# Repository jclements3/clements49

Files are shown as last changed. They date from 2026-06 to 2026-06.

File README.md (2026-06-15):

# Clements 49

## Goal

Design a 49-string double-action concert pedal harp, voiced for church solo hymn playing and jazz, with a body of unidirectional + woven flax fabric, resin-infused (VARTM). Start from the TurboSquid model as the base geometry. Build the frame from flax resin-infused molds, and produce the brass parts by lost-wax / lost-PLA casting. Use multiple agents and CPUs working in parallel to achieve this goal.

## Specification

- **Strings:** 49 strings (0G to 7A; concert-tension nylon, gut, and wires)
- **Weight:** 96.5 lbs
- **Dimensions:** 75.5″ H × 40.5″ ExW

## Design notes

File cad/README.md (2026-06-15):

# Clements 49 — Parametric OpenSCAD Baseline

Parametric OpenSCAD model of the Clements 49, a 49-string double-action concert
pedal harp (flax/CF structure, brass action). This baseline exists to support
**structural and acoustic analysis** — above all, **perfecting the new soundbox
shape** — and is driven by a single-source-of-truth **string schedule** so that
the 47→49 string change propagates automatically through neck length/curve,
string spacing, soundboard length/taper, and disc/action counts.

Built for **OpenSCAD 2021.01**, authored in **millimetres**, world frame z-up,
origin at the base footprint centre, z=0 at the floor.

> `import()` in OpenSCAD 2021.01 supports **STL only**, not OBJ. The wooden
> 47-string TurboSquid base was therefore parsed to anchors (`analysis/`) and
> separately exported to STL (`reference/`) for a ghost overlay.

-----

## Directory layout

```
cad/
├── README.md              ← this file
├── MODULE_CONTRACT.md     ← per-module signatures every component honours
├── params.scad            ← all dims / anchors / tunables / colour + MATERIAL SWITCH
├── strings.scad           ← THE STRING SCHEDULE (single source of truth) + placement laws
├── assembly.scad          ← TOP-LEVEL model; assembles every component; toggles
├── frame/
│   ├── pillar.scad        ← module pillar()                    (flax tube / wood column)
│   ├── neck.scad          ← module neck(), neck_spine()        (woven-flax + CF spine)
│   ├── soundboard.scad    ← module soundboard(), _spine(), _wing(side)  (spine + wings)
│   ├── soundbox.scad      ← module soundbox(), soundbox_cavity(), soundbox_holes()
│   └── base.scad          ← module base() (+ pedal slots, mech cavity, CF junction pads)
├── brass/
│   └── brass.scad         ← tuning_pins(), sharping_discs(), action_plates(), pedals(), brass()
├── analysis/
│   ├── string_schedule.json   ← 49-row schedule (canonical machine source)
│   ├── string_schedule.csv    ← same, spreadsheet form
│   ├── anchors.json           ← geometry anchors from the base mesh (mm, z-up)
│   ├── raw_anchors.json       ← raw centroids before scaling/cleanup
│   ├── parse_obj.py           ← OBJ → anchors extraction
│   ├── finalize.py            ← schedule/anchor finalization
│   ├── load_basis_49.md       ← recomputed 49-string structural load basis
│   └── acoustic_baseline.md   ← cavity volume / Helmholtz / soundbox acoustic targets
└── reference/
    ├── export_stl.py          ← OpenSCAD-import helper (OBJ→STL via trimesh/blender)
    ├── whole_harp.stl         ← 47-string wooden base, full
    └── frame_only.stl         ← 47-string wooden base, frame only (ghost overlay)
```

`params.scad` and `strings.scad` are **include-only** files (data + functions,
no top-level geometry). Every component file `include`s both, so each resolves
all of its dimensions from the same source. `assembly.scad` `use<>`s the
component files (modules only, no stray self-preview) and `include`s the two
data files.

-----

## The string schedule is the single source of truth

`strings.scad` (data mirrored in `analysis/string_schedule.json` /
`.csv`) is the **one place** the instrument's string set is defined: 49 rows,
idx 0..48, each with note, octave, `f0_hz`, `vib_len_mm`, `tension_N`, and
material class (wire / gut-or-nylon-low / -mid / nylon-high).

Everything geometric is derived from it through functions, never hard-coded:

- **`string_count()` / `indices()`** — drive every per-string loop.
- **`string_pin_pos(i)`** — tuning-pin point on the neck pin-line → neck curve
  length and the count of tuning pins, ferrule seats, and sharping discs.
- **`string_t_board(i)` / board span** — the soundboard eyelet positions and
  the `board_span_mm` length.
- **Spacing law** (parametric, see below) — neck pin-line length and the
  soundboard span + bass→treble width taper.

### How 47 → 49 propagates

Changing the schedule from 47 to 49 rows is a **single data edit** in
`strings.scad`. From there:

- **Neck** — `neck()` hulls section slabs between every `string_pin_pos(i)`, so
  two extra pins lengthen the pin-line (~+20 mm) and the harmonic curve grows
  automatically; ferrule seats are punched at every pin.
- **String spacing** — two-locus spacing law (parametric):
  - **Neck (pin line):** essentially constant pitch `s_neck ≈ 10.0 mm`
    center-to-center, so 49 pins span (49−1)·10.0 = 480 mm of pin line.
  - **Soundboard (eyelet line):** spacing *grows treble→bass*,
    `s_board(idx) = s_treble + (s_bass − s_treble)·((48−idx)/48)^0.85`, with
    `s_treble = 6.5 mm`, `s_bass = 24.0 mm`. Its cumulative sum sets the board
    span (~1078 mm) and drives the 380→70 mm bass→treble width taper.
  - All four knobs (`s_neck`, `s_treble`, `s_bass`, exponent) are parameters.
- **Soundboard** — `board_span_mm` and the eyelet line follow the schedule;
  `board_taper_coupling` ties the bass-wing growth to the spacing law.
- **Soundbox** — adds a synthetic bass-extension station below section 0 so the
  bass corner reaches ~50 mm farther to host the new bass string (B0).
- **Brass** — `tuning_pins()`=49, `action_discs()`=2·49=98, `pedals()`=7 (fixed
  by the diatonic-class system), action-plate segments `ceil(49/1.6)=31`.

### Resolving the "0G–7A" / 49-string spec naming

The spec calls for **49 strings labeled "0G–7A"**. The standard concert pedal
harp is **47 strings = C1..G7** (oct1 C1–B1 = 7; oct2–6 = 5×7 = 35; oct7 C7–G7
= 5; total 47). A strictly contiguous diatonic run does **not** cleanly give
"G..A" endpoints at exactly 49 from a single literal reading, so the spec is read
as octave-block extremes (bottom block "0", top block "7") rather than literal
end-string letters, and the conflict is stated rather than papered over.

**Adopted resolution (per project direction):** keep the standard 47-string
C1..G7 core and add **both** extra strings in the **bass** — **A0** and **B0**,
the two diatonic steps below C1. Treble caps at **G7** (no A7). Final range =
**A0 .. G7 = 49 strings** (idx 0 = A0, idx 48 = G7). Every string is a natural;
the double-action pedals raise each diatonic class 0/1/2 semitones, so the
schedule is the all-natural reference set, A4 = 440 Hz, equal temperament.

**Justification.** *Acoustic:* a two-string bass extension (A0 ≈ 27.5 Hz, B0 ≈
30.9 Hz) puts the most added fundamental weight exactly where the church/hymn
solo voice works hardest — the bottom octave — and grows the bass corner of the
soundbox/board where the extra cavity and radiating area are wanted. *Structural:*
both strings at the bass end extend the neck pin line (~+35 mm) and board (~+81 mm)
at one corner; the load basis is recomputed on this real geometry (see below).

**Mapping to the base model:** idx 0 (A0) and idx 1 (B0) are NEW groups inserted
below `harp_string_00`; idx 2..48 map to `harp_string_00..46` (the original
C1..G7). The measured 47-string anchor endpoints are re-anchored to C1 (idx 2)
and G7 (idx 48); A0,B0 extrapolate below the bass end (`strings.scad`
`ORIG_BASS_IDX`/`ORIG_TREBLE_IDX`). Disc/action and tuning-pin counts increase
from 47 to 49 (two new fork/discs + pins at the bass end).

-----

## Material switch: wood ↔ flax

The master switch is **one line** in `params.scad`: `material = "flax"`. It
selects the committed flax-resin structure (materials.md §6) or the wooden
47-string reference. Components **never branch on `material` directly** — they
read only the params accessors (`wall_soundbox()`, `soundboard_thickness()`,
`pillar_od()/pillar_wall()`, `wall_base()`, colour helpers `as_shell()`,
`as_carbon()`, `as_tonewood()`, `as_brass()`), so the switch drives thickness,
section, hidden CF spine presence, and colour uniformly.

Because each component `include`s its own copy of `params.scad` (an include is a
variable import; the last file-scope assignment wins), the canonical way to flip
the **whole** instrument is to edit that one line **or** drive it from the CLI:

```
openscad -D 'material="flax"' cad/assembly.scad   # committed flax-resin (default)
openscad -D 'material="wood"' cad/assembly.scad   # wooden 47-string-style reference
```

Representative differences the switch produces: pillar 50 mm OD / 8 mm wall hollow
flax tube vs 60 mm solid wood column; soundboard 10.2 mm flax sandwich
(2×1.6 skin + 7.0 core) vs 13.1 mm solid plate; base 6 mm flax monocoque vs 18 mm
solid wood; the CF spine in `neck`/`soundboard` is emitted only in flax mode.
**Brass action parts stay brass in both builds** (real harps use brass action
regardless), so brass geometry does not branch on `material`.

-----

## Soundbox tunables — perfecting the new shape

The soundbox is the analysis focus. All knobs live in `params.scad` (acoustic
group) and feed `frame/soundbox.scad`; the cross-section is a super-ellipse whose
exponent comes from `cavity_fill_factor` and whose semi-axes are area-normalised
so integrated cavity area = `cavity_fill_factor` × bounding-ellipse area.
`soundbox_cavity()` returns the inner air volume as a positive solid for
Helmholtz / volume analysis. At default `cavity_fill_factor = 0.62` the cavity
measures ~45.6 L (acoustic_baseline.md target ~45.4 L, band 40–51 L).

| Tunable | Effect | Range (default) |
|---|---|---|
| `cavity_fill_factor` | wedge↔full-ellipse cross-section → cavity volume / Helmholtz pitch | 0.55–0.70 (0.62) |
| `body_depth_profile` | per-station depth multiplier; deeper = more volume, lower f_H, warmer | 0.85–1.20× |
| `body_width_profile` | per-station across-string width; widens bass corner | 0.85–1.20× |
| `body_length_scale` | stretch of the bass→treble long axis (tracks schedule span) | 1.00–1.10 |
| `bass_corner_bulge` | extra depth+width at the lowest sections for the B0 extension | 1.00–1.25 |
| `back_curvature_radius` | transverse crown radius of the back shell | 200 mm → flat (∞) |
| `back_liveness` | back-panel compliance dead↔live (thins back skin) | 0 (dead) – 1 (live) |
| `soundhole_count` | number of back soundholes → total area S, f_H, Q | 3–6 (5) |
| `soundhole_scale` | global hole-area multiplier → Helmholtz pitch / damping | 0.7–1.4× |
| `soundhole_grade_exp` | bass→treble hole-size grading exponent | 0.5–1.5 |
| `soundhole_axis_offset` | hole-column placement along back centreline | 0.2–0.8 of length |
| `wall_thickness` | flax shell wall (Helmholtz L_eff, shell stiffness/mass) | 3–6 mm |

Coupled board knobs (`board_span`, `board_width_bass/treble`, `board_crown_radius`,
`core_depth`, `skin_thickness`, `board_taper_coupling`) also live in the same
group; `board_span` and the taper are single-sourced from the schedule.

-----

## Rendering

```
# Preview / render the whole instrument:
openscad cad/assembly.scad

# Headless STL render:
openscad -o /tmp/clements49.stl cad/assembly.scad
```

Top-level toggles in `assembly.scad` (override on the CLI with `-D name=true/false`):

| Toggle | Default | Shows |
|---|---|---|
| `show_frame` | true | pillar + neck + soundboard + soundbox + base |
| `show_brass` | true | tuning pins + sharping discs + action plates + pedals |
| `show_strings` | true | simple cylinders straight from the schedule |
| `show_reference` | false | faint STL ghost of the 47-string wooden base |
| `show_cavity` | false | soundbox inner air volume (analysis aid) |

Example: render just the soundbox cavity for volume study —
`openscad -D show_frame=false -D show_brass=false -D show_strings=false -D show_cavity=true cad/assembly.scad`.

Each component file also has a `$preview`-guarded self-preview, so opening it
alone in the GUI shows that part, while headless `-o` export of the bare file
emits nothing (by design — see verify notes below).

-----

## MOLDS DEFERRED

**No casting molds or mold cavities are generated in this baseline, by hard
directive.** The two added strings will move geometry (neck curve, board
span/taper, soundbox bass corner), so any mold authored now would be obsolete
the moment the schedule or soundbox tunables move. **Analysis and the parametric
baseline come first; molds come only after the geometry is frozen.**

What is in place instead are clean **hooks**, so adding molds later is additive,
not a rewrite:

- Every structural part is authored as a **single positive module** that a future
  offset-shell can wrap (`pillar()`, `neck()/neck_spine()`,
  `soundboard()/_spine()/_wing()`, `soundbox()/soundbox_cavity()`, `base()`).
  Each file carries a comment marking where a casting-pattern / mold-cavity
  offset-shell would attach.
- `soundbox_cavity()` already returns the inner volume as a positive solid —
  the natural seed for a future core/cavity tool.
- Brass: `brass_pattern_scale()` (= 1.015, the 1.5 % shrink oversize) is defined
  and referenced **only in comments/echo** as a future opt-in pattern step; it is
  never applied to as-used geometry. No sprue, gating, or cavities exist.

When the geometry is frozen, mold work wraps these modules — it does not modify
them.

-----

## Verify results (honest)

OpenSCAD 2021.01. Each file was parse/eval-checked (`-o …csg`) and, where it
produces geometry, render-checked to STL.

| File | Parse/eval | Render | Notes |
|---|---|---|---|
| `params.scad` | PASS (exit 0, no errors) | n/a | Include-only (params + functions, no top-level geometry). STL export reports "Current top level object is empty" and exits non-zero — **expected and acceptable** for an include-only file. No ERROR. |
| `strings.scad` | PASS (exit 0, no errors) | n/a | Include-only (schedule data + functions). Empty-top-level on export, as designed. No ERROR. No code changes. |
| `frame/pillar.scad` | PASS | PASS | Renders in flax (default) and wood (`-D material="wood"`). |
| `frame/neck.scad` | PASS | PASS | Hull sweep renders to a valid non-empty STL (~86 KB). |
| `frame/soundboard.scad` | PASS (exit 0; 3 info ECHOes: material=flax, U_len=1078 mm, eyelets=49) | PASS | Bare-file headless export emits nothing — top-level geometry is guarded by `if (sb_preview && $preview)`; `$preview` is false under `-o`. A wrapper calling `soundboard();` renders a manifold solid (222 facets, 438 verts, 2 volumes, ~10 s, 46 KB). Guard is the idiomatic include-by-assembly pattern; not changed. |
| `frame/soundbox.scad` | PASS (exit 0; ECHO diagnostics only) | **`render_ok=false` for the bare file, BY DESIGN** | Top-level geometry is guarded at line 336 by `if ($preview) _soundbox_selfpreview();`; `$preview` is false under `-o`, so bare-file export yields an empty top level (~47 KB stub, no real geometry, exit 1). This is a library meant to be `use<>`d by the assembly, like `params`/`strings`. **The geometry itself is valid:** via the assembly / a direct call, `soundbox()` renders a watertight solid (2408 facets), wood override renders, and `soundbox_cavity()` measures **45.6 L** (target 45.4 L). No ERROR; no syntax fix applied (changing the guard would be a redesign, not a low-risk fix). |
| `frame/base.scad` | PASS (exit 0; ECHO diagnostics) | PASS | Module-definition file; top-level call guarded by `PREVIEW_base = false`. With `-D material="wood" -D PREVIEW_base=true` renders a valid manifold (41 facets, 2 volumes). |
| `brass/brass.scad` | PASS | PASS | Full STL render completes, no errors/warnings (~7.8 MB mesh; 49 pins, 98 discs, 31 plate segs, 7 pedals). |
| `assembly.scad` | PASS | PASS | Top-level model assembles cleanly. |

**Summary:** all nine files parse/eval with exit 0 and **no ERROR output**.
Every geometry-producing module renders to a valid manifold STL when invoked
(directly or via the assembly). The only `render_ok=false` is `soundbox.scad`'s
*bare-file* headless export, which is the intended `$preview`-guarded
empty-top-level condition for a library file — not a defect. No syntax errors
were found and no code was changed during verification.

### Known follow-ups (carried in the analysis, not yet applied)

- The neck curve currently lerps a straight chord between the measured 47-string
  pin-line endpoints rather than threading the full curved tuning-pin polyline;
  refitting the harmonic arc to the regenerated 49-pin polyline needs
  `strings.scad` to expose intermediate curve control points (out of scope here).
- `pin_line_bass/treble_mm` in `params.scad` are still the **47-string** anchor
  values; disc/plate counts already scale to 49, but the pin-line endpoints
  should be re-derived once the neck refits for +1 bass / +1 treble (~+20 mm).
- Part dimensions for brass (pin/disc/plate/pedal sizes) are `[est]` placeholders
  flagged inline.
- Per `analysis/load_basis_49.md`, the structural load basis should be re-run on
  the regenerated 49-pin line once the neck/board geometry is refit.

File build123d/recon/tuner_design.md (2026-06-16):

# Compact brass worm-drive harp tuner — design concept

Adapts the worm-and-wheel principle of the "Guitar tuners that actually work" design
(noamtsvi, CC-BY-NC — concept only, not their geometry) into a harp-appropriate
**brass** geared tuner that replaces the simple turned pin. Self-locking worm gearing
gives fine, stable tuning that holds string tension.

## Architecture (per string)
- **String post** — Ø4.5 mm brass post with a Ø1.2 mm string hole; the string winds on it
  (replaces the pin). The worm **wheel** is integral with / fixed to the post.
- **Worm wheel** — module 0.4, 10 teeth, pitch Ø4.0 / OD Ø4.8 mm.
- **Worm** — single-start (z1=1), pitch Ø5.0 / OD Ø5.8 mm; **lead angle 4.6°** → self-locking
  (< friction angle, so string tension cannot back-drive it). Ratio **10:1**.
- **Drive** — a **hex socket** (4 mm A/F) on the worm's outboard end; turned with a hex
  driver (no finger knob). Worm axis points OUTWARD (toward the player), where there's room.
- **Brass receiver** — cast brass body **co-moulded into the VARTM flax-resin neck**: placed
  in the mould, flax/resin infuses around it and keys into its anchor holes. Carries the
  string load into the composite and provides the post + worm bearing bores. The tuner
  assembles into the receiver.

## Packaging (the binding constraint: neck pitch)
Footprint **along the neck = 11.4 mm**; outward (toward player) = 14.0 mm (room there).
Adjacent-pin pitch on the neck: treble 11.7, median 18.7, bass ≥30 mm.

| region | pitch | fit |
|---|---|---|
| treble | 11.7 mm | FITS, **+0.3 mm only** — razor-thin, no tolerance margin |
| median | 18.7 mm | fits, +7.3 mm |
| bass | ≥30 mm | fits, +18.6 mm |

The unit is asymmetric (worm to one side), so the post is **not centred** in its slot;
units must all nest the same handedness.

## Coupled trade-offs
- **Self-locking vs fit:** a low lead angle (self-locking) wants a larger worm; fit wants
  small gears. Reconciled at module 0.4 / worm Ø5.0 / wheel Ø4.8, but the teeth are small.
- **Strength:** worm-wheel torque ≈ string_tension × post_radius ≈ 261 N × 2.25 mm ≈ 587 N·mm
  at the bass. Module-0.4 brass teeth holding 100–261 N need a **tooth-root stress check**
  before finalising. The bass (highest load) has the most room → can use bigger gears there.

## Honest recommendation
Geared tuners are viable across the bass and mid. The **treble is marginal** (0.3 mm). Options:
1. **Two gear sizes** — robust gears on bass/mid, minimum gears on treble.
2. **Plain turned pins on the top ~octave** (lowest tension, easiest to tune) + geared elsewhere.
3. Push module to 0.35 and/or nest receivers front/back along the neck for the treble.

## Status / next
Packaging + gear sizing validated (`tuner_concept.py` → `tuner_concept.svg`,
`tuner_params.json`). NEXT: build the 3D parametric brass parts (receiver, post+wheel,
worm) in build123d, verify the assembly within the envelope, then tooth-stress check.
Tooth geometry in the concept is representational; cuttable involute/worm teeth are a
dedicated step (or sourced gears).

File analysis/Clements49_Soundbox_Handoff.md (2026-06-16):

# Clements 49 — Limaçon Soundbox: Geometry Handoff

A flax-composite soundbox for the 49-string (A0–G7) "Clements 49" concert pedal harp,
voiced warm. The cross-section is a **limaçon of Pascal**. This document fixes the
geometry, the orientation frame, the wall logic, and where the soundboard Bézier plugs
in, and ends with a runnable SVG of the section and an OpenSCAD generator.

---

## 1. The one-line idea

> **Outer mold line = a limaçon at `a:b = 2`** (so the stringbar lands on a *flat*),
> **inner mold line = a free-form graded wall** (thin to sing, ribbed to hold the
> string tension). Sections are cut perpendicular to the raked stringbar and lofted
> bass→treble; the soundboard outline only sets how wide each section is.

---

## 2. Coordinate frame & orientation

All from the 49 board pins (the grommet line) in `strings_49.json`. The stringbar axis
is the principal axis of those pins.

| vector | value | meaning |
|---|---|---|
| `û` (U_AXIS) | `[0.523, 0, 0.852]` | stringbar axis, raked **31.6°** from vertical, lies in the x–z plane |
| `ŷ` (Y_MINOR) | `[0, 1, 0]` | soundboard **width** direction = limaçon **minor** side |
| `n̂` (N_BOARD) | `[-0.852, 0, 0.523]` | soundboard **normal**, in x–z |
| belly | `[0.852, 0, -0.523]` = −n̂ | dimple→belly, hangs **underneath** (−z) |

**Section plane is perpendicular to `û`.** Its two in-plane axes are `ŷ` and `n̂`, and
`ŷ × n̂ = û` (right-handed), which is why the two limaçon diameters land in *different*
coordinate planes:

- **minor axis (width)** runs along **`ŷ`** → reads in the **y–z** plane;
- **major axis (depth / belly)** runs along **`n̂`** → reads in the **x–z** plane, going −z.

That split is not a contradiction — it's what happens when the section plane is tilted
(perpendicular to a raked axis) instead of aligned to a coordinate plane.

---

## 3. Cross-section geometry

### 3.1 Outer = limaçon, `a:b = 2`  (the flat seat)

Polar form `r = a + b·cos θ`. Convexity is governed by the sign of
`g(θ) = r² + 2r′² − r·r″`, which for this curve reduces to

```
g(θ) = a² + 3ab·cos θ + 2b²
g_min = g(π) = a² − 3ab + 2b² = (a − b)(a − 2b)
```

| ratio | `g_min` | shape |
|---|---|---|
| `a < b` | — | inner loop (curve threads the origin) |
| `a = b` | — | cardioid (cusp at origin) |
| `b < a < 2b` | `< 0` | **dimpled** — genuine concave indentation |
| **`a = 2b`** | **`= 0`** | **flat point at θ=π — convex boundary** |
| `a > 2b` | `> 0` | strictly convex (egg) |

We use **`a = 2b`** for the outer: at θ=π the curvature is exactly zero, so the outer
surface is **flat** right where the stringbar meets it. A straight bar wants a flat seat,
not a pocket — that is the whole reason for the choice. (Earlier drafts used `a < 2b`,
which puts a *concave* dent there; wrong for a straight bar.)

At `a:b = 2` the section is **380 wide × 345 deep** at the bass, ratio **d/w = 0.91**.

### 3.2 Inner = free-form graded wall

The inner curve is **not** a limaçon and is not tied to `a:b`. It is the outer offset
inward by a thickness `t(θ)` that varies around the section. That single freedom carries
the structural job without touching the outer shape.

---

## 4. The proportions lesson (why this split is the fix)

A *true* limaçon has its width-to-depth ratio **locked** by `a:b` — for every dimpled
ratio the perpendicular width is the *larger* dimension and the dimple→belly depth the
*smaller* one. You cannot independently choose width and depth and still have a limaçon;
forcing it (scaling x and y by different factors) breaks `r = a + b·cos θ` and yields a
distorted egg, not a limaçon.

The resolution: **only the outer is a true limaçon** (fixed `a:b = 2`, fixed 0.91 ratio,
scaled uniformly by the soundboard width). **The inner is free**, so all the
thick/thin tuning lives there. No stretching, no conflict.

---

## 5. Wall-thickness rationale

The strings pull **ΣT ≈ 9,269 N** total, of which **~5 kN** presses down through the
grommets onto the board, as a line load along the stringbar (θ=180). The grading follows
that load path:

| zone | θ | thickness | why |
|---|---|---|---|
| **rib** | ≈ 180° (stringbar line) | **~24 mm** | takes the concentrated string-anchor / down-bearing load |
| **radiating board** | flanks of θ=180° | **~3.5 mm** | this face is the radiator; thin = it moves freely |
| **structural belly** | ≈ 0° (back) | **~8 mm** | closes the box, carries the reaction, radiates less |

This is the "thick enough to hold / thin enough to sing" requirement, resolved by
**grading the inner wall**, not by one uniform thickness. The rib carries the load so the
board on either side can stay thin and vibrate.

> **Caveat — these thicknesses are first-pass.** They were set with representative
> flax-composite stiffness to fix the *proportions*, not your layup. Final values need
> your fiber fraction / ply schedule and an FEA pass. Treat them as the starting point,
> not the answer.

---

## 6. Soundboard Bézier control

The soundboard outline is (almost) a **teardrop**: fat rounded bass tapering to a treble
point. Its **half-width along the stringbar is the only thing it controls** — it sets how
wide each limaçon section is, station by station. Nothing else in the geometry depends on
it.

In the generator this is the single function:

```scad
function w_half(s) = HW_BASS * pow(1 - s, TEAR_EXP);   // first-cut teardrop
```

Replace the body with your Bézier evaluated at `s ∈ [0,1]` (bass→treble) returning the
**half-width in mm**. Everything downstream — outer scale, inner offset, the loft —
updates automatically. The outer `a:b` stays 2 regardless.

---

## 7. Acoustic note (independent of section shape)

The A0 cavity (Helmholtz) resonance is driven by **volume and the back sound-holes**, not
the cross-section profile. Target **A0 ≈ 130 Hz**, placed just under the first board mode
(~150 Hz), which wants **~35 L** behind the board plus the graded back holes
(~240 cm² total, 5 holes). The holes are **not** cut by the generator — subtract them from
the belly face afterward. Changing `a:b`, the teardrop, or the wall does not move A0 as
long as the enclosed volume is held.

---

## 8. Lessons learned (so they don't recur)

1. **Superellipses are not limaçons.** `y = D(1−|2x/W|ⁿ)^{1/n}` is a superellipse; don't
   label it limaçon-family.
2. **Sections are perpendicular to the *raked* stringbar**, not cut in horizontal
   (constant-z) planes. The board is raked ~32°.
3. **Axes:** width = `ŷ` (minor, y–z); depth/belly = `n̂` (major, x–z, −z). Don't swap
   them; the soundboard width is the y extent, not the x–z one.
4. **Never anisotropically scale a limaçon** to hit an arbitrary W×D box — it stops being
   a limaçon (the "weird ellipse"). Uniform scale only.
5. **The outer dimple is `a = 2b` (flat), not `a < 2b` (concave).** A straight stringbar
   seats on a flat. The tension thickening belongs to the **inner** wall, which is free.

---

## 9. Open items

- [ ] Replace `w_half(s)` with the real soundboard Bézier (half-width profile).
- [ ] Final wall thicknesses from your flax layup + FEA (current values are first-pass).
- [ ] Cut the 5 back sound-holes from the belly face; tune total area to hold A0 ≈ 130 Hz.
- [ ] Reconcile the ~10–20% frame scatter between `strings_49.json` and the earlier
      `soundbox_reloft_data.json` once rendered against the real STLs.
- [ ] Render the OpenSCAD (I can't here) and confirm the polyhedron is manifold /
      right-side-out.

---

## 10. Section — SVG (bass station)

```svg
<svg xmlns="http://www.w3.org/2000/svg" viewBox="0 0 600 470" font-family="sans-serif">
  <!-- wall = outer with inner as even-odd hole -->
  <path d="M300.0,405.2 L310.9,404.9 L321.8,404.0 L332.6,402.5 L343.3,400.3 L353.8,397.6 L364.1,394.3 L374.2,390.5 L384.1,386.0 L393.6,381.1 L402.9,375.6 L411.8,369.7 L420.3,363.3 L428.3,356.5 L436.0,349.3 L443.2,341.7 L449.9,333.7 L456.2,325.5 L461.9,317.0 L467.1,308.2 L471.8,299.2 L475.9,290.1 L479.6,280.9 L482.6,271.5 L485.2,262.1 L487.2,252.6 L488.6,243.2 L489.6,233.8 L490.0,224.4 L489.9,215.2 L489.4,206.1 L488.4,197.1 L486.9,188.4 L485.0,179.8 L482.7,171.5 L480.0,163.4 L476.9,155.6 L473.5,148.1 L469.8,140.9 L465.8,134.0 L461.5,127.5 L457.0,121.3 L452.3,115.4 L447.4,109.8 L442.4,104.6 L437.2,99.8 L432.0,95.3 L426.6,91.1 L421.2,87.3 L415.8,83.7 L410.3,80.5 L404.8,77.6 L399.4,75.0 L394.0,72.7 L388.7,70.6 L383.4,68.8 L378.3,67.2 L373.2,65.8 L368.2,64.7 L363.3,63.7 L358.5,62.8 L353.9,62.1 L349.3,61.6 L344.9,61.1 L340.5,60.8 L336.3,60.5 L332.2,60.3 L328.2,60.2 L324.2,60.1 L320.4,60.1 L316.6,60.0 L312.8,60.0 L309.1,60.0 L305.5,60.0 L301.8,60.0 L298.2,60.0 L294.5,60.0 L290.9,60.0 L287.2,60.0 L283.4,60.0 L279.6,60.1 L275.8,60.1 L271.8,60.2 L267.8,60.3 L263.7,60.5 L259.5,60.8 L255.1,61.1 L250.7,61.6 L246.1,62.1 L241.5,62.8 L236.7,63.7 L231.8,64.7 L226.8,65.8 L221.7,67.2 L216.6,68.8 L211.3,70.6 L206.0,72.7 L200.6,75.0 L195.2,77.6 L189.7,80.5 L184.2,83.7 L178.8,87.3 L173.4,91.1 L168.0,95.3 L162.8,99.8 L157.6,104.6 L152.6,109.8 L147.7,115.4 L143.0,121.3 L138.5,127.5 L134.2,134.0 L130.2,140.9 L126.5,148.1 L123.1,155.6 L120.0,163.4 L117.3,171.5 L115.0,179.8 L113.1,188.4 L111.6,197.1 L110.6,206.1 L110.1,215.2 L110.0,224.4 L110.4,233.8 L111.4,243.2 L112.8,252.6 L114.8,262.1 L117.4,271.5 L120.4,280.9 L124.1,290.1 L128.2,299.2 L132.9,308.2 L138.1,317.0 L143.8,325.5 L150.1,333.7 L156.8,341.7 L164.0,349.3 L171.7,356.5 L179.7,363.3 L188.2,369.7 L197.1,375.6 L206.4,381.1 L215.9,386.0 L225.8,390.5 L235.9,394.3 L246.2,397.6 L256.7,400.3 L267.4,402.5 L278.2,404.0 L289.1,404.9 L300.0,405.2 Z M299.8,397.2 L310.5,396.9 L320.9,396.1 L331.2,394.6 L341.5,392.6 L351.6,390.0 L361.5,386.8 L371.2,383.2 L380.7,378.9 L389.9,374.2 L398.7,369.0 L407.3,363.4 L415.4,357.3 L423.2,350.8 L430.6,343.9 L437.6,336.6 L444.1,329.0 L450.1,321.2 L455.7,313.0 L460.7,304.6 L465.3,296.1 L469.3,287.3 L472.9,278.5 L475.9,269.5 L478.4,260.4 L480.4,251.4 L481.9,242.3 L482.9,233.3 L483.4,224.3 L483.4,215.4 L483.0,206.6 L482.1,198.0 L480.8,189.6 L479.0,181.3 L476.9,173.3 L474.4,165.5 L471.5,157.9 L468.3,150.7 L464.8,143.7 L461.0,137.0 L457.0,130.6 L452.7,124.5 L448.3,118.8 L443.6,113.4 L438.8,108.3 L433.9,103.5 L428.8,99.1 L423.7,95.0 L418.5,91.2 L413.3,87.7 L408.1,84.6 L402.8,81.7 L397.6,79.1 L392.4,76.7 L387.2,74.7 L382.1,72.8 L377.1,71.2 L372.2,69.8 L367.3,68.6 L362.6,67.6 L357.9,66.7 L353.3,66.0 L348.9,65.4 L344.5,64.9 L340.3,64.5 L336.1,64.3 L332.0,64.3 L328.0,64.6 L324.1,65.4 L320.3,67.1 L316.5,69.9 L312.8,73.6 L309.1,77.7 L305.5,81.5 L301.8,83.7 L298.2,83.7 L294.5,81.5 L290.9,77.7 L287.2,73.6 L283.5,69.9 L279.7,67.1 L275.9,65.4 L272.0,64.6 L268.0,64.3 L263.9,64.3 L259.7,64.5 L255.5,64.9 L251.1,65.4 L246.7,66.0 L242.1,66.7 L237.4,67.6 L232.7,68.6 L227.8,69.8 L222.9,71.2 L217.9,72.8 L212.8,74.7 L207.6,76.7 L202.4,79.1 L197.2,81.7 L191.9,84.6 L186.7,87.7 L181.5,91.2 L176.3,95.0 L171.2,99.1 L166.1,103.5 L161.2,108.3 L156.4,113.4 L151.7,118.8 L147.3,124.5 L143.0,130.6 L139.0,137.0 L135.2,143.7 L131.7,150.7 L128.5,157.9 L125.6,165.5 L123.1,173.3 L121.0,181.3 L119.2,189.6 L117.9,198.0 L117.0,206.6 L116.6,215.4 L116.6,224.3 L117.1,233.3 L118.1,242.3 L119.6,251.4 L121.6,260.4 L124.1,269.5 L127.1,278.5 L130.7,287.3 L134.7,296.1 L139.3,304.6 L144.3,313.0 L149.9,321.2 L155.9,329.0 L162.4,336.6 L169.4,343.9 L176.8,350.8 L184.6,357.3 L192.7,363.4 L201.3,369.0 L210.1,374.2 L219.3,378.9 L228.8,383.2 L238.5,386.8 L248.4,390.0 L258.5,392.6 L268.8,394.6 L279.1,396.1 L289.5,396.9 L300.2,397.2 Z" fill="#b9966a" fill-rule="evenodd" stroke="none"/>
  <path d="M300.0,405.2 L310.9,404.9 L321.8,404.0 L332.6,402.5 L343.3,400.3 L353.8,397.6 L364.1,394.3 L374.2,390.5 L384.1,386.0 L393.6,381.1 L402.9,375.6 L411.8,369.7 L420.3,363.3 L428.3,356.5 L436.0,349.3 L443.2,341.7 L449.9,333.7 L456.2,325.5 L461.9,317.0 L467.1,308.2 L471.8,299.2 L475.9,290.1 L479.6,280.9 L482.6,271.5 L485.2,262.1 L487.2,252.6 L488.6,243.2 L489.6,233.8 L490.0,224.4 L489.9,215.2 L489.4,206.1 L488.4,197.1 L486.9,188.4 L485.0,179.8 L482.7,171.5 L480.0,163.4 L476.9,155.6 L473.5,148.1 L469.8,140.9 L465.8,134.0 L461.5,127.5 L457.0,121.3 L452.3,115.4 L447.4,109.8 L442.4,104.6 L437.2,99.8 L432.0,95.3 L426.6,91.1 L421.2,87.3 L415.8,83.7 L410.3,80.5 L404.8,77.6 L399.4,75.0 L394.0,72.7 L388.7,70.6 L383.4,68.8 L378.3,67.2 L373.2,65.8 L368.2,64.7 L363.3,63.7 L358.5,62.8 L353.9,62.1 L349.3,61.6 L344.9,61.1 L340.5,60.8 L336.3,60.5 L332.2,60.3 L328.2,60.2 L324.2,60.1 L320.4,60.1 L316.6,60.0 L312.8,60.0 L309.1,60.0 L305.5,60.0 L301.8,60.0 L298.2,60.0 L294.5,60.0 L290.9,60.0 L287.2,60.0 L283.4,60.0 L279.6,60.1 L275.8,60.1 L271.8,60.2 L267.8,60.3 L263.7,60.5 L259.5,60.8 L255.1,61.1 L250.7,61.6 L246.1,62.1 L241.5,62.8 L236.7,63.7 L231.8,64.7 L226.8,65.8 L221.7,67.2 L216.6,68.8 L211.3,70.6 L206.0,72.7 L200.6,75.0 L195.2,77.6 L189.7,80.5 L184.2,83.7 L178.8,87.3 L173.4,91.1 L168.0,95.3 L162.8,99.8 L157.6,104.6 L152.6,109.8 L147.7,115.4 L143.0,121.3 L138.5,127.5 L134.2,134.0 L130.2,140.9 L126.5,148.1 L123.1,155.6 L120.0,163.4 L117.3,171.5 L115.0,179.8 L113.1,188.4 L111.6,197.1 L110.6,206.1 L110.1,215.2 L110.0,224.4 L110.4,233.8 L111.4,243.2 L112.8,252.6 L114.8,262.1 L117.4,271.5 L120.4,280.9 L124.1,290.1 L128.2,299.2 L132.9,308.2 L138.1,317.0 L143.8,325.5 L150.1,333.7 L156.8,341.7 L164.0,349.3 L171.7,356.5 L179.7,363.3 L188.2,369.7 L197.1,375.6 L206.4,381.1 L215.9,386.0 L225.8,390.5 L235.9,394.3 L246.2,397.6 L256.7,400.3 L267.4,402.5 L278.2,404.0 L289.1,404.9 L300.0,405.2 Z" fill="none" stroke="#5a2d0c" stroke-width="2.2"/>
  <path d="M299.8,397.2 L310.5,396.9 L320.9,396.1 L331.2,394.6 L341.5,392.6 L351.6,390.0 L361.5,386.8 L371.2,383.2 L380.7,378.9 L389.9,374.2 L398.7,369.0 L407.3,363.4 L415.4,357.3 L423.2,350.8 L430.6,343.9 L437.6,336.6 L444.1,329.0 L450.1,321.2 L455.7,313.0 L460.7,304.6 L465.3,296.1 L469.3,287.3 L472.9,278.5 L475.9,269.5 L478.4,260.4 L480.4,251.4 L481.9,242.3 L482.9,233.3 L483.4,224.3 L483.4,215.4 L483.0,206.6 L482.1,198.0 L480.8,189.6 L479.0,181.3 L476.9,173.3 L474.4,165.5 L471.5,157.9 L468.3,150.7 L464.8,143.7 L461.0,137.0 L457.0,130.6 L452.7,124.5 L448.3,118.8 L443.6,113.4 L438.8,108.3 L433.9,103.5 L428.8,99.1 L423.7,95.0 L418.5,91.2 L413.3,87.7 L408.1,84.6 L402.8,81.7 L397.6,79.1 L392.4,76.7 L387.2,74.7 L382.1,72.8 L377.1,71.2 L372.2,69.8 L367.3,68.6 L362.6,67.6 L357.9,66.7 L353.3,66.0 L348.9,65.4 L344.5,64.9 L340.3,64.5 L336.1,64.3 L332.0,64.3 L328.0,64.6 L324.1,65.4 L320.3,67.1 L316.5,69.9 L312.8,73.6 L309.1,77.7 L305.5,81.5 L301.8,83.7 L298.2,83.7 L294.5,81.5 L290.9,77.7 L287.2,73.6 L283.5,69.9 L279.7,67.1 L275.9,65.4 L272.0,64.6 L268.0,64.3 L263.9,64.3 L259.7,64.5 L255.5,64.9 L251.1,65.4 L246.7,66.0 L242.1,66.7 L237.4,67.6 L232.7,68.6 L227.8,69.8 L222.9,71.2 L217.9,72.8 L212.8,74.7 L207.6,76.7 L202.4,79.1 L197.2,81.7 L191.9,84.6 L186.7,87.7 L181.5,91.2 L176.3,95.0 L171.2,99.1 L166.1,103.5 L161.2,108.3 L156.4,113.4 L151.7,118.8 L147.3,124.5 L143.0,130.6 L139.0,137.0 L135.2,143.7 L131.7,150.7 L128.5,157.9 L125.6,165.5 L123.1,173.3 L121.0,181.3 L119.2,189.6 L117.9,198.0 L117.0,206.6 L116.6,215.4 L116.6,224.3 L117.1,233.3 L118.1,242.3 L119.6,251.4 L121.6,260.4 L124.1,269.5 L127.1,278.5 L130.7,287.3 L134.7,296.1 L139.3,304.6 L144.3,313.0 L149.9,321.2 L155.9,329.0 L162.4,336.6 L169.4,343.9 L176.8,350.8 L184.6,357.3 L192.7,363.4 L201.3,369.0 L210.1,374.2 L219.3,378.9 L228.8,383.2 L238.5,386.8 L248.4,390.0 L258.5,392.6 L268.8,394.6 L279.1,396.1 L289.5,396.9 L300.2,397.2 Z" fill="none" stroke="#7a3b10" stroke-width="1.3"/>
  <!-- stringbar on the flat outer -->
  <line x1="150" y1="58" x2="450" y2="58" stroke="#0f5c4d" stroke-width="4"/>
  <circle cx="300" cy="60" r="5" fill="#0f5c4d"/>
  <!-- string stubs -->
  <line x1="180" y1="44" x2="180" y2="58" stroke="#3b7bbf" stroke-width="1"/><line x1="210" y1="44" x2="210" y2="58" stroke="#3b7bbf" stroke-width="1"/><line x1="240" y1="44" x2="240" y2="58" stroke="#3b7bbf" stroke-width="1"/><line x1="270" y1="44" x2="270" y2="58" stroke="#3b7bbf" stroke-width="1"/><line x1="300" y1="44" x2="300" y2="58" stroke="#3b7bbf" stroke-width="1"/><line x1="330" y1="44" x2="330" y2="58" stroke="#3b7bbf" stroke-width="1"/><line x1="360" y1="44" x2="360" y2="58" stroke="#3b7bbf" stroke-width="1"/><line x1="390" y1="44" x2="390" y2="58" stroke="#3b7bbf" stroke-width="1"/><line x1="420" y1="44" x2="420" y2="58" stroke="#3b7bbf" stroke-width="1"/>
  <!-- labels -->
  <text x="300" y="20" text-anchor="middle" font-size="13" font-weight="bold">Clements 49 — limaçon section (bass)</text>
  <text x="455" y="50" font-size="11" fill="#0f5c4d">stringbar on FLAT outer (a=2b)</text>
  <text x="318" y="92" font-size="11" fill="#7a1f1f">rib (inner) — string tension</text>
  <text x="60" y="250" font-size="11" fill="#1f4e79">thin radiating</text>
  <text x="60" y="264" font-size="11" fill="#1f4e79">board ≈ 3.5 mm</text>
  <text x="300" y="450" text-anchor="middle" font-size="11" fill="#5a2d0c">structural belly ≈ 8 mm</text>
  <text x="300" y="40" text-anchor="middle" font-size="10" fill="#444">width 380 mm   ·   depth 345 mm   ·   d/w 0.91</text>
</svg>
```

---

## 11. OpenSCAD generator

```scad
// ======================================================================
//  Clements 49 — limaçon soundbox  (parametric generator)
//
//  OUTER cross-section = limaçon with a:b = 2  -> single FLAT point at
//  theta=180, so the stringbar seats on a flat (not a notch).
//  INNER cross-section = free-form graded wall (board / rib / belly);
//  it owes nothing to a:b and carries the structural job.
//
//  Sections are cut PERPENDICULAR to the raked stringbar and lofted
//  bass -> treble. Units mm, angles degrees.
// ======================================================================

// ---------------------------------------------------------------- FRAME
// (principal axis of the 49 board pins in strings_49.json)
U_AXIS  = [0.523, 0, 0.852];   // stringbar axis, raked 31.6 deg from vertical (x-z plane)
Y_MINOR = [0, 1, 0];           // soundboard WIDTH direction = limacon minor side (y)
N_BOARD = [-0.852, 0, 0.523];  // soundboard normal (x-z). belly = -N_BOARD = [0.852,0,-0.523] (-z, "underneath")

P_BASS   = [-297.4, -2.5,  111.8];   // bass   board pin  (loft start)
P_TREBLE = [ 417.2, -2.5, 1262.8];   // treble board pin  (loft end)

// ----------------------------------------------------------- PARAMETERS
AB        = 2.0;    // a:b for the OUTER. ==2 gives the flat seat.
                    //  >2 = rounder (no flat), <2 = concave dent. KEEP AT 2 for the outer.
NSEC      = 41;     // loft stations bass->treble
MPTS      = 160;    // points per ring (even, >=80)

// --- soundboard half-width profile  (FIRST-CUT teardrop) --------------
//     This is the ONLY thing the soundboard Bezier controls.
//     Replace the body of w_half(s) with your Bezier evaluation, s in [0,1].
HW_BASS   = 190;    // half-width at the bass (mm) -> 380 wide
TEAR_EXP  = 0.6;    // teardrop taper exponent (first cut only)
function w_half(s) = HW_BASS * pow(1 - s, TEAR_EXP);   // <<< BEZIER HOOK >>>

// --- wall thickness  (free-form INNER) --------------------------------
T_BOARD   = 3.5;    // thin radiating board (flanks of the stringbar)
T_BELLY   = 8.0;    // structural belly (closes the box)
T_RIB     = 24.0;   // string-anchor rib peak, at theta=180 (the stringbar line)
RIB_SIG   = 10;     // rib angular half-width (deg) -> narrower = sharper rib

// -------------------------------------------------------------- HELPERS
function vsum(v,i=0,a=0) = i<len(v) ? vsum(v,i+1,a+v[i]) : a;
function lim_Wunit(a,b)  = max([for(t=[0:2:359]) abs((a+b*cos(t))*sin(t))]);

// OUTER ring in section-plane coords [minor, depth]; flat top at depth 0
function outer2d(s) =
  let(a=AB, b=1,
      sc    = (2*w_half(s)) / (2*lim_Wunit(a,b)),  // UNIFORM scale -> stays a true limacon
      lxmin = -(a-b))                              // flat/dimple end of the symmetry axis
  [ for(i=[0:MPTS-1])
      let(t=360*i/MPTS, r=a+b*cos(t))
      [ (r*sin(t))*sc, -((r*cos(t))-lxmin)*sc ] ]; // depth: 0 at flat top -> -D at belly

// wall thickness as a function of ring index (free-form)
function t_of(i) =
  let(t=360*i/MPTS,
      base = (T_BELLY+T_BOARD)/2 + (T_BELLY-T_BOARD)/2*cos(t),  // thin top, thick belly
      rib  = (T_RIB-T_BOARD)*exp(-pow((t-180)/RIB_SIG,2)))      // rib spike at stringbar
  base + rib;

// INNER ring = OUTER offset inward by t_of() along the local inward normal
function inner2d(s) =
  let(o=outer2d(s), m=len(o),
      cx=vsum([for(p=o)p[0]])/m, cy=vsum([for(p=o)p[1]])/m)
  [ for(i=[0:m-1])
      let(p=o[i], pn=o[(i+1)%m], pp=o[(i+m-1)%m],
          tx=pn[0]-pp[0], ty=pn[1]-pp[1], L=norm([tx,ty]),
          nx=ty/L, ny=-tx/L,
          sg=sign((cx-p[0])*nx+(cy-p[1])*ny), tt=t_of(i))
      [ p[0]+nx*sg*tt, p[1]+ny*sg*tt ] ];

// map a section-plane point [minor, depth] to world 3D at station s
function P_at(s)      = P_BASS + s*(P_TREBLE - P_BASS);
function to3d(s,ring) = let(P=P_at(s)) [ for(p=ring) P + p[0]*Y_MINOR + p[1]*N_BOARD ];

// skin a list of equal-length 3D rings into a closed solid
module skin(rings) {
  n=len(rings); m=len(rings[0]);
  pts =[for(r=rings) for(p=r) p];
  side=[for(i=[0:n-2]) for(j=[0:m-1])
          [ i*m+j, i*m+(j+1)%m, (i+1)*m+(j+1)%m, (i+1)*m+j ]];
  cap0=[for(j=[0:m-1]) (m-1-j)];          // first cap (reversed winding)
  cap1=[for(j=[0:m-1]) (n-1)*m+j];        // last cap
  polyhedron(points=pts, faces=concat(side,[cap0],[cap1]), convexity=10);
}

// ---------------------------------------------------------------- BUILD
SS = [for(k=[0:NSEC-1]) k/(NSEC-1)];

module soundbox_limacon() {
  difference() {
    skin([for(s=SS) to3d(s, outer2d(s))]);   // outer solid
    skin([for(s=SS) to3d(s, inner2d(s))]);   // remove the cavity
  }
  // Back sound-holes are NOT cut here; subtract them from the belly face
  // (theta ~ 0 side) after this, sized per the acoustic note (~240 cm^2 total).
}

soundbox_limacon();

// Notes for integration:
//  * Drop this into harp_scaffold.scad in place of the empty
//    `module soundbox_limacon(){}` slot; comment out the trailing
//    assembly calls if you only want to view the box.
//  * I cannot run OpenSCAD in my sandbox, so the polyhedron winding is
//    reasoned, not rendered. If it renders inside-out, swap cap0/cap1 or
//    reverse the side quad order. F6 + a manifold check is the acceptance test.

```

---

## 12. Using it

1. Paste §11 into `harp_scaffold.scad` where the empty `module soundbox_limacon(){}`
   slot is. Comment out the five trailing assembly calls if you just want the box.
2. Tune `AB` (leave at 2), `HW_BASS`/`w_half`, and the `T_*` wall params.
3. `F6`, then run a manifold check. If it renders inside-out, reverse the cap or
   side-quad winding in `skin()`.
4. Subtract the back sound-holes from the belly face.
5. Drop in the soundboard Bézier when it's locked — only `w_half` changes.

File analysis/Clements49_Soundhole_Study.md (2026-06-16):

# Clements 49 — Back Sound-Hole Sizing & Placement Study

Companion to the soundbox handoff. This sizes and places the back sound-holes to land
the air resonance **A0 ≈ 130 Hz**, just under the first soundboard mode (~150 Hz), and
keeps the holes large enough to double as stringing access.

---

## 1. Model

Lumped Helmholtz resonator, calibrated to Le Carrou's concert-harp measurements (×1.123):

```
A0 = 1.123 · (c / 2π) · sqrt( A_total / ( V · L_eff ) )
L_eff = t_wall + 1.7 · a_eq        (a_eq = per-hole equivalent radius)
```

- `c` = 343 m/s, `t_wall` = 8 mm (the structural belly the holes pass through).
- `A_total` = sum of hole areas; `V` = enclosed cavity volume.
- `1.7·a_eq` is the two-sided orifice end correction; holes are treated as parallel necks.

This is a lumped estimate. The real instrument is a **coupled** air-cavity / soundboard
system, so treat A0 as a starting target to verify by measurement on the prototype, not a
guaranteed number.

---

## 2. Cavity volume (from the box as drawn)

The volume drives everything, so it's taken from the actual loft, not assumed:

| quantity | value |
|---|---|
| loft length (stringbar) | 1,355 mm |
| outer limaçon volume | 64.8 L |
| **cavity (inner, after the graded wall)** | **58.2 L** |

> **Correction to earlier notes.** I had been carrying a 35 L target and a ~240 cm² hole
> figure. Both were wrong for this box. The a = 2b limaçon is a large round section
> (380 × 345 at the bass), so the enclosed cavity is **58 L**, and the matching hole area
> is **smaller** than 240 cm². This study supersedes those numbers.

---

## 3. Required hole area

Solving the model for A0 = 130 Hz at V = 58.2 L, t_wall = 8 mm, 5 holes:

| target | result |
|---|---|
| A0 | 130 Hz |
| **total hole area** | **≈ 165 cm²** |
| per-hole equivalent radius | 32 mm |
| effective neck length L_eff | 63 mm |

---

## 4. Hole sizing (5 holes, graded bass→treble)

Areas graded larger at the bass (more low-end radiation, bigger body, easier hand access
where the heavy strings are). Ovals at ~1.6:1, long axis running along the body.

| hole | station s | area (cm²) | oval long × short (mm) |
|:--:|:--:|:--:|:--:|
| #1 (bass) | 0.12 | 43.5 | 94 × 59 |
| #2 | 0.30 | 39.2 | 89 × 56 |
| #3 | 0.48 | 34.3 | 84 × 52 |
| #4 | 0.66 | 28.3 | 76 × 47 |
| #5 (treble) | 0.84 | 20.2 | 64 × 40 |
| **total** | | **165.5** | |

The four bass-side holes clear ~75 mm in the long axis — a hand fits for stringing. #5 is
deliberately small (the treble strings need least access and the body is narrow there).

---

## 5. Placement (belly centerline)

Centers lie on the back/belly centerline, `P(s) + D(s)·belly`, with
`belly = [0.852, 0, -0.523]` and depth `D(s)` the dimple→belly distance. World mm:

| hole | x | y | z |
|:--:|:--:|:--:|:--:|
| #1 | 60 | −2 | 81 |
| #2 | 154 | −2 | 310 |
| #3 | 244 | −2 | 541 |
| #4 | 328 | −2 | 776 |
| #5 | 401 | −2 | 1018 |

Spacing leaves solid wall at both ends and between holes for the rib/ring structure. Cut
each oval through the 8 mm belly wall, long axis along the local body direction.

---

## 6. Sensitivity

| change | A0 |
|---|---|
| total area 132 cm² (−20%) | 122 Hz |
| **total area 165 cm² (nominal)** | **130 Hz** |
| total area 199 cm² (+20%) | 137 Hz |
| volume 46.6 L (−20%) | 145 Hz |
| **volume 58.2 L (nominal)** | **130 Hz** |
| volume 69.9 L (+20%) | 119 Hz |

A0 scales roughly with √(area) and 1/√(volume). The +20% area case (137 Hz) still clears
the ~150 Hz board mode; the −20% volume case (145 Hz) starts to crowd it, so if the built
cavity comes out smaller than modeled, trim hole area to drop A0 back down. **Tuning lever
on the finished box: shave hole area to lower A0, open it to raise A0** — easier than
changing volume after the fact.

See `holes.png` for the to-scale hole layout and the A0-vs-area curve with the V = 52–64 L
band.

---

## 7. Open items

- [ ] Verify A0 on the prototype (tap test / cavity excitation); adjust hole area to tune.
- [ ] Confirm the 8 mm belly thickness at each hole location after the wall study/FEA;
      L_eff (hence A0) moves with wall thickness.
- [ ] Check holes don't land on a soundboard-mode antinode or a structural rib once those
      are placed.
- [ ] If access needs push the holes larger than 165 cm² total, raise A0 above 130 —
      either accept it (stay < 150) or add cavity volume to compensate.

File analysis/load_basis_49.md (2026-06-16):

# Clements 49 — Structural load basis (A0..G7, refit on the real 49-pin line)

Structural load basis for the finalized **49-string** schedule **A0..G7** (scientific, idx 0..48),
**recomputed on the actual re-anchored 49-pin line** (not the proportionally-mapped 47-string mesh).
This supersedes the earlier B0..A7 / 47-mesh pass. Every figure is tagged **[model]** (computed from
the finalized schedule + the refit geometry), **[est]** (first-order estimate, stated assumptions), or **[lit]**.

Reproduce with `analysis/refit_49.py` (writes `string_schedule.{json,csv}` and `refit_49_loads.json`).

Inputs:
- String schedule: `analysis/string_schedule.json` (49 strings A0..G7, per-string `tension_N`).
- Geometry anchors: `analysis/anchors.json` — measured 47-string endpoints, **re-anchored** so the
  measured bass/treble endpoints are C1 (idx 2) and G7 (idx 48); A0 (idx 0) and B0 (idx 1) are
  **extrapolated below the bass end**, lengthening the neck pin line by ~34.7 mm and the board string
  line by ~81 mm at the bass corner. Scale 8.8598 mm/unit.

Frame convention: z-up, mm; bass→treble is +x; column/player side is −x; y is across-body. Strings,
pin line, and pillar lie essentially in the x–z plane, so load resolution is done in x–z.

-----

## Results (A0..G7, refit)

| Quantity | Value | Source |
|---|---|---|
| Total string tension ΣT | **9,269.4 N (2,083.8 lbf)** | [model] |
| String angle to soundboard (rake off board long axis U) | **35.3° median (range 21.3–37.9°)** | [model] |
| Perpendicular pull on board | **5,305 N** (tension-weighted per-string) / 5,578 N at 37° | [model]/[est] |
| In-plane longitudinal pull on board | **7,588 N** (tension-weighted per-string) | [model] |
| Neck peak bending moment | **≈855 N·m** (distributed pin loads, peak at x/L≈0.46) | [model] |
| Pillar axial force | **≈9,228 N** (resultant 9,237 N projected on column axis) | [model] |

-----

## Method and assumptions

### 1. Total tension ΣT  [model]
Direct sum of the 49 per-string `tension_N` for A0..G7 = **9,269.4 N**; ÷ 4.44822 = **2,083.8 lbf**.
Versus the prior B0..A7 set (9,219.2 N): dropping the treble A7 (97.3 N) and adding the bass A0
(147.5 N, [est] from the bass length/tension trend) **raises ΣT by ~50 N** — the bass extension adds
net tension, as expected.

### 2. String angle to soundboard  [model]
Per-string rake θ = acute angle between the string (eyelet→pin, in x–z) and the board long axis U
(bass→treble chord of the string-exit line). On the **refit** geometry: median **35.3°**, range
21.3–37.9° — notably closer to the **37° design target** than the 30° measured on the raw 47-string
mesh, because re-anchoring places the bass strings on a steeper, longer rake.

### 3. Perpendicular and in-plane pull on the board  [model]/[est]
Tension-weighted per-string vector sum: Σ T·sinθᵢ = **5,305 N** perpendicular; Σ T·cosθᵢ = **7,588 N**
in-plane. At the 37° design target ΣT·sin37° = **5,578 N** — so the refit perpendicular pull (5.3 kN
measured / 5.6 kN @37°) now brackets the **5,500 N conservative board-sizing value** in materials.md
§1/§2.2, which is retained. In-plane is dominated by the high-tension shallow-rake bass strings.

### 4. Neck peak bending moment  [model]
Neck modeled as a beam simply supported between the bass-most pin (A0) and the treble-most pin (G7)
along their chord (span ≈833 mm). Each pin applies its string tension toward its eyelet; the bending
driver is the component perpendicular to the support chord. Discrete-load shear/moment diagram gives
reactions RA ≈ 4,253 N, RB ≈ 3,506 N (ΣW⊥ ≈ 7,759 N) and **peak |M| ≈ 855 N·m at x/L ≈ 0.46**
(mid-span, near the C4/G4 register). This is up from the 793 N·m B0..A7/47-mesh pass — the +34.7 mm
bass pin-line extension lengthens the moment arm — and lands within the 793–850 N·m band predicted
there. **943 N·m is retained as a conservative reserve** (the simply-supported idealization ignores
frame end-fixity, which reduces peak M).

### 5. Pillar axial force  [model]
Resultant of the 49 string pulls (each T along eyelet→pin) in x–z = (−515, 9,237) N, |R| ≈ 9,238 N,
nearly vertical. The column axis (anchors' top/bottom) is ≈2.2° off vertical; projecting R onto it
gives pillar axial **≈9,228 N** in compression. Up from 8,251 N (47-mesh) — the steeper refit rake
puts more of ΣT into the near-vertical resultant the pillar reacts. Consistent with the ≈9 kN quoted
in materials.md §6.3; feeds the Euler-buckling pillar sizing (SF 3, K≈1, L≈1.7 m).

-----

## Comparison to the prior B0..A7 / 47-mesh pass

| Quantity | Prior (B0..A7, 47-mesh) | This refit (A0..G7, 49-pin line) | Note |
|---|---|---|---|
| ΣT | 9,219.2 N | 9,269.4 N | +50 N: drop A7, add A0 (bass) |
| Rake median | 30.1° | 35.3° | refit bass rake steeper; nearer 37° target |
| Perp pull | 4,032 N / 5,548 @37° | 5,305 N / 5,578 @37° | brackets the 5,500 N design value |
| In-plane pull | 7,201 N | 7,588 N | higher with added bass tension |
| Neck peak moment | ≈793 N·m | ≈855 N·m | +arm from bass extension; <943 reserve |
| Pillar axial | ≈8,251 N | ≈9,228 N | steeper rake → larger vertical resultant |

**Net:** the refit on the real A0..G7 pin line raises every load modestly (more bass tension, steeper
rake, longer bass moment arm). All stay within the conservative design reserves (5,500 N board pull,
943 N·m neck moment). Re-run this basis if the spacing law or the measured anchors change.

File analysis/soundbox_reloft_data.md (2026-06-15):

# Clements 49 — Soundbox re-loft data

**Units:** mm.  **Frame:** z-up; origin=base footprint centre (x,y), z=0 floor; +x bass->treble; soundboard face +y (front); body bulges -y (back)

**Enclosed cavity (air) volume:** **53.08 L**  (outer solid 56.76 L; wall 4.0 mm). Measured from the rendered `soundbox_cavity()` solid.

> NOTE on the y-axis: current sections are super-ellipses **centred on y=0**, so the box bulges symmetrically in front of (+y) and behind (−y) the soundboard plane (board at y≈+1.9). Physically the box should sit **behind** the board (−y only). The limaçon re-loft should pin the FRONT edge at y≈0 and bulge only to −y.

## 1. Cross-sections (horizontal slices, normal +z), bass→treble

Full ordered (x,y) outlines in JSON → `sections[].outline_xy`.

| z | x_center | width_x | depth_y | y_front | y_back | pts |
|---|---|---|---|---|---|---|
| 130 | -104.4 | 236.5 | 580.6 | 290.3 | -290.3 | 149 |
| 258 | -11.2 | 227.9 | 549.8 | 274.9 | -274.9 | 107 |
| 440 | 87.4 | 198.7 | 457.6 | 228.8 | -228.8 | 105 |
| 622 | 155.1 | 179.6 | 364.0 | 182.0 | -182.0 | 153 |
| 804 | 256.4 | 164.1 | 291.2 | 145.6 | -145.6 | 149 |
| 986 | 351.7 | 134.7 | 227.4 | 113.7 | -113.7 | 149 |
| 1168 | 467.5 | 95.6 | 156.4 | 78.2 | -78.2 | 149 |
| 1290 | 536.7 | 61.5 | 113.8 | 56.9 | -56.9 | 149 |

## 2. Soundbox axis
Length **1329.2 mm** over z [130, 1290]. Points (x,0,z): (-104.4,130); (-11.2,258); (87.4,440); (155.1,622); (256.4,804); (351.7,986); (467.5,1168); (536.7,1290)

## 2b. Attachment footprints

**Soundbox→base** (join z=126.1): base part footprint x[-494.5, 494.5] y[-266.9, 266.9], base top z=140.0. Soundbox end outline (149 pts) in JSON `attachments.soundbox_to_base`. Soundbox bass cap seats onto the base top (base spans z 0..140). Contact = the soundbox end outline below, dropped onto the base top plane (z=140).

**Soundbox→neck** (join z=1323.0): neck pin-line treble end [476.15, 20.84, 1404.38], neck section [40, 33] mm, pillar top [-303.11, 54.0, 1859.75]. Soundbox end outline (149 pts) in JSON `attachments.soundbox_to_neck`. Neck (super-ellipse 40x33 mm at this end) ties into the treble-top of the body; the pillar top closes the frame triangle at the point above.

## 3. Soundboard

- String span A0→G7 (3D chord): **1310.4 mm**; U-length ≈ 1149.0 mm.
- Width taper: **380.0 → 70.0 mm**.
- Rake: **37.0° design** (35.3° measured).
- 49 string crossings in JSON `soundboard.string_crossings`. A0=[-247.1, 1.9, 117.4], G7=[441.7, 1.9, 1232.2].

## 4. Sound-holes (back, −y)
| k | z | long | short |
|---|---|---|---|
| 0 | 393.9 | 120.0 | 85.0 |
| 1 | 559.2 | 105.0 | 74.8 |
| 2 | 724.5 | 90.0 | 64.5 |
| 3 | 889.9 | 75.0 | 54.2 |
| 4 | 1055.2 | 60.0 | 44.0 |

## 5. Construction
- continuous lofted super-ellipse shell (NOT faceted staves); no internal ribs/bulkheads modeled in the soundbox (soundboard carries a CF/woven spine; base has bulkheads). Back transverse crown radius = 200 mm (param).
- Sources: SVG plate (renders/clements49_plate.svg); STL reference (cad/reference/*.stl, gitignored); original OBJ (extract/, gitignored). No STEP/BREP (geometry is mesh + parametric OpenSCAD).

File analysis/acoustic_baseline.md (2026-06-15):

# Clements 49 — Acoustic Baseline (soundbox shape definition)

Defines the current (47-string reference model) acoustic state and the parametric levers
to expose in `soundbox.scad` for perfecting the **new 49-string soundbox shape**.
All geometry in millimetres, z-up, frame per `anchors.json`. Numbers are tagged
**[model]** (from the extracted geometry / string schedule), **[lit]** (handbook/literature
class values) or **[est]** (first-order estimate with stated assumptions).

This document deliberately *improves conceptually* on the single-slice cavity placeholder
that `materials.md §8` flags: the cavity is integrated from the **seven measured
cross-sections** as a lofted, leaning taper, and the Helmholtz model uses the **back
soundhole array** combined into an equivalent aperture rather than one slice.

---

## 1. Current soundbox acoustic state (47-string reference)

### 1.1 Cavity volume — lofted from cross-sections **[est]**

The soundbox is a lofted taper between the seven measured sections (perpendicular to z,
marching +x with height because the body leans). Each station's cross-section is modelled
as an ellipse of semi-axes `wx/2 × dy/2` with a **fill factor 0.62** (the real harp
cross-section is a rounded wedge / half-ellipse, not a full ellipse), integrated
trapezoidally along the body arc length (Δx,Δz between section centroids), plus a bass-end
extension cap (~80 mm) and a treble tip cone.

| fill factor | cavity volume |
|---|---|
| 0.55 | 40.3 L |
| **0.62 (adopted)** | **45.4 L** |
| 0.70 | 51.3 L |

**Adopted cavity volume V ≈ 45 L (0.045 m³)**, with a defensible band of **40–51 L**
driven by the cross-section fill assumption. This supersedes the single-slice placeholder.

### 1.2 Soundhole (back) total area **[est]**

Concert-harp soundboxes vent through a graded column of **5 oval "eyes" on the back**,
large at the bass end, small toward treble. Modelled as ellipses (long × short axis):
120×85, 110×78, 95×68, 78×56, 60×44 mm.

**Total soundhole area S ≈ 253 cm² (25,300 mm²)**, equivalent single-hole radius
a_eq ≈ 90 mm. (The exact diameters live in the source asset's back panel/`harp_back_bolt_*`
region and should be re-measured against the asset; this is the order-correct estimate.)

### 1.3 Helmholtz cavity resonance **[est]**

`f_H = (c/2π)·√( S / (V·L_eff) )`, c = 343 m/s, the 5 holes combined into one equivalent
aperture of area S, effective neck length `L_eff = wall_thickness + 1.7·a_eq`
(≈ 4 mm shell + 153 mm end correction = 157 mm).

**f_Helmholtz ≈ 103 Hz** (G2–G♯2 region).

Sensitivity (fixed S, L_eff):

| cavity V | f_H |
|---|-----|
| 30 L | 127 Hz |
| 40 L | 110 Hz |
| **45 L** | **103 Hz** |
| 50 L | 98 Hz |

So the air resonance lands in the **low-mid (~100 Hz, G2 ± a few semitones)** — it props
up the bottom-mid, not the true bass. This is normal for harps: the lowest strings
(B0 ≈ 31 Hz, C1 ≈ 33 Hz) radiate well below the air mode and rely on board/string
coupling, not the cavity, for their fundamentals.

### 1.4 Soundboard fundamental — order of magnitude **[est]**

The board is a spine-and-wings sandwich (thin spruce/cedar skins over Nomex/balsa core,
CF+flax spine; `materials.md §6.1`). Modelled bounds:

- Effective sandwich rigidity D ≈ 460 N·m (1.5 mm spruce skins, 6 mm core), areal mass
  μ ≈ 1.4 kg/m².
- Long-axis (U) pinned-beam mode over the 1,078 mm span → ~24 Hz (lower bound; ignores
  bracing/spine and transverse coupling).
- Simply-supported plate first mode (1.078 × 0.22 m) → ~600 Hz (upper bound; overstiff,
  too much transverse stiffness assumed).

The boundary conditions and orthotropy span more than an order of magnitude; the honest
statement is the **coupled whole-board first mode (T(1,1)) sits in the ~90–150 Hz region**
**[lit]** for instruments of this size, close to and coupling with the ~100 Hz Helmholtz
mode (the classic air/board doublet). **Order of magnitude: ~10² Hz.** Closing this number
needs measured flax/skin E, ρ, the chosen core depth and crown radius (`materials.md §8`).

---

## 2. Parametric levers for the new 49-string soundbox

Each lever below maps to a parameter name implemented in `soundbox.scad`. The soundbox is
generated as a **lofted taper between control sections** (improving on the single slice):
the control sections are driven by these parameters so the shape, cavity and apertures are
co-designed rather than fixed.

| param | acoustic role | sensible range |
|---|---|---|
| `cavity_fill_factor` | Cross-section fullness (full-ellipse vs rounded-wedge). Sets cavity volume → Helmholtz pitch and low-mid support. | 0.55–0.70 (default 0.62) |
| `body_depth_profile` | Multiplier vector on `depth_y` at each control station (back stand-off from board). Deeper = more volume, lower f_H, warmer; tapers fore-aft. | 0.85–1.20× of model depths |
| `body_width_profile` | Multiplier on `width_x` (across-string) per station. Widens bass corner for bass radiation; couples to board taper. | 0.85–1.20× |
| `body_length_scale` | Stretch of the body long axis (bass→treble span). Tracks the string-schedule span; +2 strings lengthens the bass corner. | 1.00–1.10 |
| `bass_corner_bulge` | Extra depth+width concentrated at the bass end (lowest 2 sections) to host the B0 extension without globally enlarging the box. | 1.00–1.25 |
| `back_curvature_radius` | Transverse crown radius of the back shell (cross-section curvature). Smaller R = stiffer, deader back; larger R = flatter, "live" back adds low end (`materials.md §6.2` open item). | 200 mm – flat (∞) |
| `back_liveness` | Effective back-panel compliance switch/scale (stiff/dead ↔ live), realised as back skin thickness/core. Live back broadens/lowers the air-coupled response. | 0 (dead) – 1 (live) |
| `soundhole_count` | Number of back soundholes. More holes raise S → raise f_H and lower Q (more damped, broader). | 3–6 (default 5) |
| `soundhole_scale` | Global multiplier on hole areas. Sets total S → f_H pitch and venting/damping. | 0.7–1.4× |
| `soundhole_grade_exp` | Bass→treble size grading exponent (large at bass). Shapes where venting happens along the body. | 0.5–1.5 |
| `soundhole_axis_offset` | Placement of the hole column along the back centreline (fraction of body length). Moves the acoustic centre of the aperture. | 0.2–0.8 of length |
| `wall_thickness` | Flax shell wall (enters L_eff and shell stiffness/mass). Thicker = lower f_H slightly, deader, heavier. | 3–6 mm |
| `board_span` | Soundboard U-length (bass→treble). Single-source from string schedule; drives board mode + body length. | 1000–1130 mm (spec 1078) |
| `board_width_bass` / `board_width_treble` | Board taper endpoints (V-width). Spec 380→70 mm; sets wing area → radiating efficiency and the 37° string rake fan. | bass 340–420, treble 55–90 mm |
| `board_crown_radius` | Longitudinal crown (camber) of the soundboard. Shell action against the ~5,500 N perpendicular pull; raises board stiffness/fundamental and projection. | 1500 mm – flat |
| `core_depth` | Sandwich core thickness in the wings. Dominant lever on board stiffness vs mass → board fundamental and radiation. | 4–12 mm |
| `skin_thickness` | Tonewood radiating-skin gauge. Trades stiffness/mass (board mode) vs cosmetic-veneer regime. | 0.8–2.5 mm |
| `board_taper_coupling` | Couples board span+taper to the string schedule's `s_board` law (bass extension grows the bass wing/corner automatically). | on/off + 0.0–1.0 blend |

These are the parameters returned in `tunable_params` (structured output) and to be
implemented in `soundbox.scad`. Material/layup choices (skin material, core type, back
liveness as a build) ride on the wood↔flax switch from `materials.md §6`.

---

## 3. Bass-extension implications (added low strings) **[est]**

The 49-string schedule adds **B0 (idx 0, f₀ ≈ 30.9 Hz, vibrating length 1,354.5 mm)** below
C1, and A7 above G7. The bass end is what grows.

- **Board length:** integrating the schedule's `s_board(idx)` spacing law, the board span
  grows **+~31 mm (+4.2%)** going 47→49 strings, almost entirely at the bass end (the
  bass-most gap B0–C1 is the widest at 24.0 mm; the added treble gap A7–G7 is only 6.5 mm).
- **Bass reach:** the new B0 is 47.7 mm longer in vibrating length than the old longest
  string (C1, 1,306.8 mm), so the **bass corner of the board + neck must reach ~50 mm
  farther** to host it.
- **Cavity / depth:** the cavity supports the low-mid via the ~100 Hz Helmholtz mode, not
  the 31 Hz bass fundamentals, so the box need not be tuned an octave lower. But the added
  bass weight wants proportionally more bass-end air and board area. To keep the
  air-resonance position relative to the (now lower) bass register, target
  **cavity volume +8–15% (≈ 49–52 L)**, concentrated at the bass end via `bass_corner_bulge`:
  **bass-corner depth_y ~539 → ~590–620 mm** and **body length +~50–65 mm** at the bass end.
  Globally the rest of the taper is unchanged — the parametric `bass_corner_bulge` and
  `body_length_scale` levers isolate this growth so the treble half of the box is untouched.

**Net:** the bass extension is a *bass-corner-local* change (~+4% board length, ~+10% bass-end
volume, ~+50 mm reach), not a whole-body rescale — consistent with the schedule's
"+1 bass / +1 treble" symmetric-ish resolution that keeps 47→49 propagation incremental.

---

## 4. Open / to-close (carry into the structural + coupled-acoustic run)

- Re-measure the actual back soundhole diameters/positions from the source asset (drives S, f_H).
- Measured flax/skin E, ρ, chosen core depth and crown radius to pin the board fundamental
  (currently OOM only).
- A coupled two-DOF air/board model (Helmholtz mode + T(1,1) board mode) to predict the
  doublet split — the single-slice and even this lofted-cavity model are still uncoupled.
- Confirm fill factor against a watertight cavity boolean once the parametric shell exists
  (the reference `frame_only.stl` is a surface mesh, not usable for boolean volume).

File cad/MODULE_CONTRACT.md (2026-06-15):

# Clements 49 — Module Contract

Canonical interface every component file must expose. The assembly and all
component authors depend on these exact module names + argument lists so the
shared world frame, the string schedule, and the material switch stay
consistent across files. Generated by the foundation task.

## Shared rules (all component files)

- First two lines: `include <../params.scad>` then `include <../strings.scad>`.
  (Component files live under `cad/frame/` and `cad/brass/`, so the parent path
  is `../`.) These are the ONLY config sources; do not hard-code dimensions
  that params/strings already provide.
- World frame: z-up, millimetres, origin = base-footprint centre in x,y and
  z=0 at the floor. Bass->treble = +x. Column/player side = -x. y = across-body
  depth. Every frame module renders IN PLACE in this world frame (no local
  re-centring) so files overlay directly.
- Iterate `for (i = indices())` and read `string_*(i)`, `string_board_pos(i)`,
  `string_pin_pos(i)`. NEVER hard-code 47/49 — the count comes from
  `string_count()`. Adding strings is a data edit in `strings.scad` only.
- Material/colour: read the `material` switch indirectly via the params
  accessor helpers (`wall_*()`, `*_thickness()`, `shell_color()`,
  `string_color()`) and the `as_shell()/as_tonewood()/as_carbon()/as_brass()`
  colour-wrap modules. Do not branch on `material` yourself.
- CASTING HARD CONSTRAINT: generate NO molds/cavities this run. Each part is a
  solid `module` so a future offset-shell can wrap it. Leave clean hooks only.
- Apply `brass_pattern_scale()` ONLY when emitting a casting pattern (future);
  never to the as-used brass geometry in the assembly.

## Component module signatures (the contract)

Each frame module takes NO required args (reads params + strings). Optional
named args have defaults so callers may omit them.

### frame/pillar.scad
- `module pillar();`
  Leaning flax tube (or solid wood column) along the `pillar_bottom_mm ->
  pillar_top_mm` axis, length `pillar_length_mm`, OD `pillar_od()`, wall
  `pillar_wall()`. Solid module; future offset-shell hook.

### frame/neck.scad
- `module neck();`
  Harmonic-curve neck following the tuning-pin line (`string_pin_pos(i)` over
  `indices()`), woven-flax super-ellipse (n = `neck_superellipse_n`) section
  tapering `neck_h_end_mm` -> `neck_h_peak_mm` -> `neck_h_end_mm`, width
  `neck_w_mm`. Exposes pin-seat positions via `string_pin_pos(i)`.
- `module neck_spine();`  (optional sub-part) the CF-UD spine solid; rendered
  only when `is_flax`. Caller may union it into `neck()`.

### frame/soundboard.scad
- `module soundboard();`
  Spine-and-wings board on the board string line (`string_board_pos(i)`).
  U-length `board_span_mm`, taper `board_width_bass_mm` -> `board_width_treble_mm`,
  longitudinal crown `board_crown_radius`, total thickness
  `soundboard_thickness()` (sandwich when flax, solid plate when wood). String
  exit eyelets at `string_board_pos(i)`.
- `module soundboard_spine();` (optional) the load-carrying spine strip alone.
- `module soundboard_wing(side);` (optional, side = -1|+1) one radiating wing.

### frame/soundbox.scad  (the shape to PERFECT)
- `module soundbox();`
  Lofted leaning shell from `soundbox_section_count()` control sections via
  `soundbox_section_eff(i)` (already carries the acoustic tunables:
  `body_*_profile`, `body_length_scale`, `bass_corner_bulge`,
  `cavity_fill_factor`). Wall `wall_soundbox()`. Back crown
  `back_curvature_radius`, liveness `back_liveness`.
- `module soundbox_cavity();` (optional) the INNER lofted volume (air cavity),
  for volume/Helmholtz analysis. Solid positive of the inside; NOT a boolean
  subtraction tool this run.
- `module soundbox_holes();` (optional) `soundhole_count` graded back
  soundholes positioned by `soundhole_axis_offset`, sized by `soundhole_scale`
  and `soundhole_grade_exp`. Marked as a positive-solid hook (do not subtract
  this run unless the caller opts in).

### frame/base.scad
- `module base();`
  Monocoque base/plinth over the footprint (`base_xmin..base_xmax`,
  `base_ymin..base_ymax`, height `base_footprint_z`), wall `wall_base()`.
  CF-reinforced junctions at the pillar foot (`pillar_bottom_mm`) and body
  foot. Houses the (future) pedal mechanism — leave interior as a clean hook.

### brass/brass.scad
- `module tuning_pins();`   one cast pin per string at `string_pin_pos(i)`.
- `module sharping_discs();` double-action fork/disc pair per string near
  `string_pin_pos(i)` / the neck.
- `module action_plates();`  neck action-plate set along the pin line.
- `module pedals();`         7 pedals + linkage at the base.
- `module brass(parts = "all");`  convenience aggregator; `parts` is a string
  selecting `"pins"|"discs"|"plates"|"pedals"|"all"`. All brass modules render
  at nominal (un-shrunk) size; pattern scaling is a future, opt-in step.

## Assembly (future, not built this run)
- `assembly.scad` will `use` each component and call `pillar(); neck();
  soundboard(); soundbox(); base(); brass();` with no args, relying on the
  shared world frame for registration.

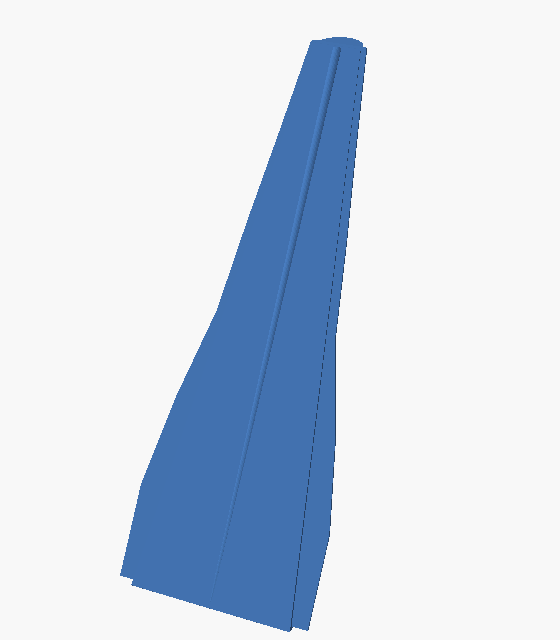
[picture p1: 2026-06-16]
openscad/soundbox.png

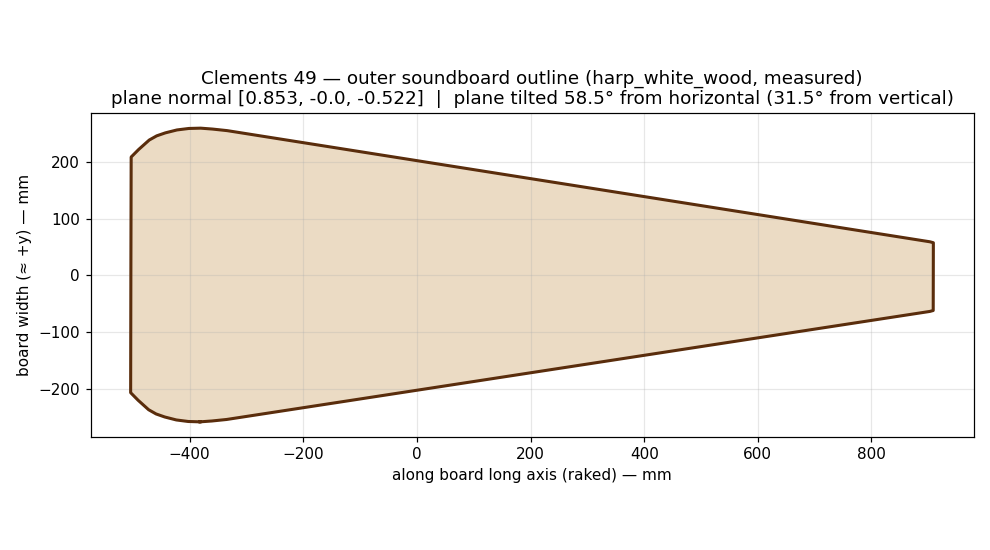
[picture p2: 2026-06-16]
analysis/soundboard_outline.png

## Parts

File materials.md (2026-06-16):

# Clements 49 — Materials Analysis & Design

Materials selection and construction design for the Clements 49 — a 49-string (0G–7A) carbon-reinforced flax concert pedal harp. Covers the governing physics, candidate material analysis, and the committed per-component decisions with layup specifications.

**Design priority:** best natural acoustic sound first, structural integrity as a hard constraint, natural/bio-based materials (flax, tonewood) preferred where they do not compromise either.

Numbers are tagged **[model]** (derived from the project structural model / string schedule), **[lit]** (literature/handbook ranges for the material class), or **[est]** (first-order estimate with stated assumptions). Material property ranges are class-typical and **must be confirmed by test on the actual fibre/resin/extraction used before committing to a layup.**

-----

## 1. Load basis

|Quantity |Value |Source |
|---|---|---|
|String set |49 strings, A0–G7 (0G–7A spec; both added in bass; ~+30% over Erard)|[model]|
|Total string tension ΣT |9,269.4 N (2,083.8 lbf) |[model]|
|String angle to soundboard (rake off long axis U)|35.3° median (range 21.3–37.9°); 37° design target|[model]|
|Perpendicular pull on board |5,305 N measured; ≈ 5,500 N @37° (design value)  |[model]/[est]|
|In-plane longitudinal pull on board |7,588 N measured |[model]|
|Neck peak bending moment (near C4/G4) |≈ 855 N·m (943 N·m retained as reserve) |[model]|
|Pillar axial force |≈ 9,228 N |[model]|
|Soundboard span |1,078 mm (C1–G7); ~1,149 mm extended for A0–G7  |[model]|
|Soundboard width taper (bass→treble) |380 → 70 mm |[model]|

> **Load basis recomputed for the finalized A0–G7 49-string set on the actual refit 49-pin line** (idx 0..48), replacing the earlier B0–A7 / 47-mesh pass. Both extra strings were added in the **bass** (A0, B0 below C1; treble caps at G7), per the adopted reading of the "0G–7A" spec. Full method, assumptions, and comparison are in `analysis/load_basis_49.md` (reproduce with `analysis/refit_49.py`). The measured 47-string anchor endpoints are re-anchored to C1 (idx 2) and G7 (idx 48); A0,B0 extrapolate below, lengthening the pin line ~35 mm and the board ~81 mm at the bass. Effects of the refit: ΣT rises ~50 N (drop treble A7, add bass A0); the bass strings sit on a steeper rake so the **median rake moves to 35.3°** (nearer the 37° target) and the perpendicular pull rises to **5,305 N** (measured) / 5,578 N @37° — bracketing the **5,500 N conservative board-sizing value** (§2.2, §6.1), which is retained. The neck peak moment rises to **≈855 N·m** (longer bass moment arm); **943 N·m is retained as a conservative reserve** (§6.4). Pillar axial ≈9,228 N confirms the ≈9 kN in §6.3.

-----

## 2. Governing physics

Five principles drive every material decision below.

**2.1 Buckling forgives low modulus; bending punishes it.** A compression column sized against Euler buckling needs diameter `D ∝ E^(−1/4)` — flax’s ~5× lower modulus than carbon costs only ~1.5× the diameter (5^0.25 ≈ 1.5). A beam in bending deflects as `1/(EI)` — *linear* in modulus, so low-E flax deflects far more. Consequence: the **pillar tolerates all-flax**, the **neck does not** and needs a carbon spine.

**2.2 The soundboard has two conflicting jobs.** It must resist ~5,500 N of perpendicular string pull (wants thick/stiff) *and* radiate sound efficiently (wants light/compliant). A uniform solid flax plate sized for the load came out 13.1 mm (solid UD) or 10.0 mm (±45/90 cross-plied) **[model]** — structurally honest but acoustically dead. The conflict is resolved by **(a)** a sandwich core, **(b)** crown, and **(c)** a load-carrying spine, none of which a single solid plate offers.

**2.3 The radiating skin sets the voice; the core supports; the spine carries load.** What the ear reads as “natural” is dominated by the radiating surface. Put the tonewood voice in a thin skin, the stiffness in a light low-damping core, and the string load in a separate spine/bracing so the radiator stays free to move. This is the proven double-top (thin tonewood skins / honeycomb core) and lattice-braced (thin top / carbon lattice) architecture from high-end lutherie.

**2.4 Place damping by intent.** Low-damping materials where you want sound (the board face); high-damping materials where you want silence (the soundbox shell). Flax’s high damping is a liability on the board and an asset on the box.

**2.5 Fibre form decides everything for natural fibres.** Only *continuous, aligned, mechanically-extracted* fibre delivers structural properties. Chopped fibre, wood “fibre” (pulp/flour), and textile “bamboo/cedar fibre” (often regenerated rayon) act as mass-adding, property-reducing filler. To use the sound of a wood (cedar, spruce, bamboo) the material must stay a **continuous strip/lamella/veneer**, never a chopped fibre.

-----

## 3. Acoustic figures of merit

Two numbers rank a soundboard material:

- **Radiation coefficient** `R = √(E/ρ³)` — efficiency of converting string energy to radiated sound. High = loud, responsive.
- **Damping** `tan δ` — low gives sustain/brightness, high gives warmth/fast decay.

|Material (UD, in-fibre) |E (GPa)|ρ (kg/m³)  |R ≈ √(E/ρ³)|Damping |Role / verdict |
|---|---|---|---|---|---|
|Spruce (along grain) |~11 |~400 |~13 |low |Benchmark radiator; unmatched (stiff + extremely light)|
|Cedar, W. red (along grain)|~8–10  |~350–400 |~12 |low |Warmer tonewood; very responsive |
|Carbon UD |130–230|1,550–1,600|~6 |very low|Loud, bright, long sustain, even; “clinical” |
|Aramid (Kevlar) UD |70–80  |~1,440 |~5 |high |Damped + weak in compression + hard to finish — avoid  |
|Bamboo (good fibre) |~25 |~1,150 |~4 |high |Slightly better radiator than flax; warm |
|Flax UD |25–30  |~1,400 |~3 |high |Warm, woody, less efficient; best of the naturals |
|Glass / basalt UD |73–90  |2,550–2,700|~2 |moderate|Too dense — dull; structural use only |

Values: spruce/cedar/glass/aramid E,ρ **[lit]**; R computed from those **[est]**. Bamboo and flax fibre properties are highly variable by source/extraction — **[lit]**, confirm by test.

**Key takeaway:** no composite fibre matches spruce’s radiation efficiency, because none combines high stiffness with spruce’s 0.4 g/cc lightness. Composites win on stability, durability, and tunability — not raw efficiency. Carbon beats flax for output/sustain but shifts the voice bright/clinical; Kevlar and glass are worse than flax for tone. The way to a genuinely *natural* sound is a **tonewood radiating skin**, not a fibre swap.

-----

## 4. Core materials (sandwich)

A sandwich gets bending stiffness from skin separation (`I ∝ separation²`) at low mass — the dominant lever on the soundboard’s structural-vs-acoustic conflict (§2.2).

|Core |ρ (kg/m³)|Shear stiffness  |Damping |Verdict for radiating board |
|---|---|---|---|---|
|Nomex honeycomb |~30–60 |high |low |**Best** — lightest, stiffest; the double-top gold standard |
|End-grain balsa |~120–220 |high (for weight)|low-ish, woody|**Excellent**, easier to work; woody, lively |
|PMI/Rohacell foam |~50–110  |good |low-ish |Stable, predictable; good all-composite option |
|PVC/SAN foam (Divinycell/Airex)|~60–200  |moderate |higher |OK structurally, less lively |
|Cork |~120–240 |low (soft) |**very high** |**Avoid in the board** — a dedicated damper; use it to *quiet* the box|

Cork is a deliberate damping/isolation material. In a radiating board it kills sustain and output. Its correct home is the soundbox shell, where deadness is wanted.

-----

## 5. Soundboard coordinate frame

Local axes used for all soundboard layup callouts:

- **U** — along the grommet / reinforcing strip; board long axis (bass↔treble); the longitudinal load path to the end blocks. Strings rake off U toward the neck.
- **V** — perpendicular to U, in the board surface; transverse, into the wings.
- **W** — through-thickness, normal to the board. Plies stack along W; **no fibres run along W** (it is only the stacking direction). Add z-reinforcement (stitching/z-pins) only if interlaminar peel appears at joints.

The board surface is the UV plane.

-----

## 6. Component design decisions

Cross-cutting principle: **carbon hidden inside as structure, flax as the natural skin/shell wherever it works, tonewood only on the radiating board face.**

### 6.1 Soundboard — double-top wings + composite spine

**Architecture:** spine-and-wings. A stiff narrow spine carries the string load longitudinally to the end blocks; the wings are freed to be thin radiators.

**Wings (radiator):**

- Thin **spruce** skins (classic harp voice, best projection) — **cedar** as the warmer, more-responsive alternative — over a **Nomex honeycomb** core (**balsa** as the easier near-equal substitute).
- Skin grain / principal stiffness run **across the strip (V)** to couple drive energy outward over the short transverse span and let the wing stay thin.
- Radiator gauge: a few mm total; far below the 13 mm solid-plate floor.

**Spine (grommet strip):**

- **CF-UD along U** — beam fibres carrying the string line to the end blocks.
- **Woven ±45 / 0/90** at the grommet bearing zone — multidirectional bearing and split-resistance at the eyelets (pure UD-U would cleave at the holes).
- Optional CF-UD reinforcement where flax stiffness falls short.

**Transition:** grade (drop/overlap) the UD-U spine plies into the wing UD-V so the stiffness step is a gradient, not a hinge/stress riser.

**Why:** tonewood skin = the natural voice (§3); light low-damping core = stiffness without mass (§4); load in the spine keeps the wings free to radiate (§2.3).

### 6.2 Soundbox (sides + back) — cored woven-flax monocoque

- **Quasi-isotropic woven flax** (0/90 + ±45), doubly-curved monocoque shell.
- Optional **foam or cork core** layer for stiffness + damping.
- **Why:** the box must be rigid, reflective, and dead so energy stays in the board and cavity. Flax’s high damping is an asset here; woven gives balanced shell stiffness with no soft axis to flap; curvature does most of the stiffening. Cork earns its place here as a damping layer — never in the board.
- *Open:* a slightly “live” back can add low end. Default to dead; keep liveness as a later tuning lever rather than over-stiffening on the assumption that rigid is always better.

### 6.3 Pillar — flax tube, UD-axial + woven hoop

- Hollow tube, ~50 mm OD **[est]**, **UD flax along the column axis** (buckling EI), with **woven ±45 / hoop** layers for torsional and local stability.
- **Why:** buckling-governed, and buckling forgives flax’s low modulus (§2.1) — ~1.5× the diameter of an equivalent carbon column. All-flax is viable; the tube is the efficient section. Add CF only if a visually slimmer column is wanted.
- Representative sizing (SF 3, K=1 pinned-pinned, L≈1.5 m, N≈9 kN) **[est]**: solid flax ≈ 47–50 mm OD vs solid CF ≈ 31 mm OD. Real axial force and length come from the project structural model.

### 6.4 Neck — CF spine in a woven-flax super-ellipse

- **CF-UD spine** along the neck length, placed at the bending extreme fibres, inside a **woven-flax super-ellipse (n=4)** section.
- Section: **40 × 58 mm** at the C4/G4 moment peak, tapering to **40 × 33 mm** at the ends **[model]**.
- **Brass ferrules/bushings at every tuning-pin hole** (pin bearing is the critical local failure mode; plate/section thickness alone cannot address it).
- **Why:** stiffness-governed at 943 N·m peak moment (§2.1). Peak bending stress on the section is ≈ 42–50 MPa **[est]** vs flax UD flexural strength ~150–250 MPa **[lit]** — so *strength* has a 3–5× margin, but *deflection* governs: flax alone deflects enough to detune the strings. CF carries the stiffness; woven flax forms the section and surface. This is the one component flax cannot do solo.

### 6.5 Base — woven flax/CF monocoque, mass low

- **Quasi-isotropic woven flax** monocoque, **CF-reinforced** at the pillar-foot and body-foot load junctions, with internal bulkheads. Ballast kept low for stability. Houses the pedal mechanism.
- **Why:** concentrated loads from pillar and body, plus tip stability (the instrument is top-heavy under ~9 kN of string pull), plus mechanism housing. Acoustically irrelevant, so optimise junction strength/stiffness and a low centre of gravity. Mass is welcome here.

-----

## 7. Material & appearance summary

|Component |Structural fibre |Radiating/skin material |Visible surface |
|---|---|---|---|
|Soundboard wings|Nomex/balsa core |Thin spruce (or cedar) skins|Tonewood (spruce/cedar)|
|Soundboard spine|CF-UD + woven flax |— (under strings) |Strip line |
|Soundbox |Woven flax (+ core) |— |Natural flax |
|Pillar |UD flax + woven flax (CF optional)|— |Natural flax |
|Neck |CF-UD spine + woven flax |— |Natural flax |
|Base |Woven flax + CF at junctions |— |Natural flax |

The **only** non-flax visible surface is the spruce/cedar board face — a deliberate trade of flax aesthetics for the best natural sound exactly where it matters most. Everything else reads as natural flax, with carbon working out of sight. Spruce/cedar (warm reddish-brown to honey) and natural flax (golden tan) are both warm naturals and coordinate well.

-----

## 8. Open items & required measurements

Closure of the design depends on the following, consistent with the project’s measurement-first discipline:

**Soundboard**

- Real flax flexural strength/modulus on the actual layup (governs the spine and any remaining solid regions).
- Core depth (sandwich) — sets wing stiffness vs mass.
- Crown radius — shell action against the perpendicular pull.
- Rib-to-rail transverse span / bracing layout.
- Tonewood skin thickness for the radiator vs cosmetic-veneer regimes.
- Wood↔composite differential-movement detailing (thin sealed skin, no rigid bond across large stiff areas) to prevent checking/delamination.

**Soundbox**

- Cavity volume, hole size/placement → Helmholtz tuning (the current cavity model is a single-slice placeholder, not a coupled cavity analysis).
- Wall core/thickness for target rigidity.

**Pillar & neck**

- Exact pillar axial force, length, and buckling-sized diameter from the project structural model against the final geometry.
- CF spine sizing in the neck for the deflection (not strength) limit.

**Fibre/material qualification (before any committed layup)**

- Measure E and ρ on the actual flax (and any bamboo) fibre/resin system; natural-fibre properties are too variable to trust handbook values.
- Insert OD / drill diameter sized to the specific ferrule thread and section thickness.

-----

## 9. Decision log (closed in this analysis)

- Soundboard: spine-and-wings; thin spruce/cedar skins over Nomex/balsa core; CF-UD + woven-flax spine; wing fibre across the strip (V), spine fibre along the strip (U).
- Soundbox: cored woven-flax quasi-iso monocoque; cork allowed here as a damping layer.
- Pillar: UD-flax + woven-hoop tube; CF optional for slimness only.
- Neck: CF-UD spine in woven-flax super-ellipse (n=4); brass ferrules at all pins.
- Base: woven-flax/CF monocoque, low mass centre, houses mechanism.
- Rejected: Kevlar (damped, weak in compression, poor finish); glass/basalt (too dense for tone); chopped natural fibre / wood “fibre” (filler, not reinforcement); cork in the radiating board; uniform solid flax soundboard (acoustically dead).

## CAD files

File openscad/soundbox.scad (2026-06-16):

// ============================================================================
// soundbox.scad  --  Harp SOUNDBOX assembly (reverse-engineered parametric model)
// ============================================================================
//
// PIPELINE: This is the SOUNDBOX pass of a reusable reverse-engineering pipeline
//   (Blender clements49.blend -> per-part analysis JSON -> per-part OpenSCAD
//    module -> this assembly). Other subsystems (strings, neck, base, ...) are
//   handled in separate passes and are NOT included here.
//
// UNITS: model units (NOT mm). All geometry is kept in the original Blender
//   world coordinates so the rebuilt soundbox sits exactly where the original
//   model did; no re-centering or rescaling is applied.
//
// COORDINATE CONVENTION (matches the source model):
//   Z = up            (model spans z 0 .. 216.5)
//   X = front(-) / back(+)
//   Y = left / right  (about +/- 36)
//   Overall model bbox: x[-62.6,62.6] y[-36.1,36.1] z[0,216.5]
//
// SOUNDBOX union bbox (5 parts; harp_wood_inside1 excluded as neck-region):
//   min [-30.07, -35.38, 15.293]   max [30.694, 60.301, 152.295]   dims ~[60.76, 95.68, 137.0]
//
// NOTE ON include vs use:
//   Each sb_*.scad part file ends with a top-level self-call (so the part can be
//   rendered standalone for verification). We therefore use<> the part files
//   here instead of include<>: use<> imports the module DEFINITIONS only and
//   suppresses those top-level calls, so the assembly below controls exactly
//   what is rendered (no accidental double-render). Each module already places
//   its geometry at the original world coords via its own multmatrix, so the
//   assembly simply calls them with no extra transform.
// ============================================================================

// ---- part modules (definitions only; top-level self-calls suppressed) ----
use <parts/sb_harp_big_side_pivot.scad>   // body shell  (loft / hull)
use <parts/sb_harp_white_wood_01.scad>    // soundboard face 1 (flat plate)
use <parts/sb_harp_white_wood_02.scad>    // soundboard face 2 (flat plate)
use <parts/sb_harp_wood_plank.scad>       // plank        (flat bar)
use <parts/sb_harp_wood_inside.scad>      // inner lining (flat plate)
// harp_wood_inside1 REMOVED: it sits at z 174.6-189.8, ABOVE the soundboard top
// (151.9) -> it is a NECK-region piece, not soundbox. To be handled in the neck pass.

// ============================================================================
// KEY DIMENSION VARIABLES  (model units; informational / drive previews)
// ============================================================================

// --- expected soundbox envelope (union of the 6 part AABBs) ---
sb_bbox_min    = [-30.07, -35.38,  15.293];
sb_bbox_max    = [ 30.694, 60.301, 152.295];   // (harp_wood_inside1 excluded -> neck)
sb_dims        = [ sb_bbox_max[0]-sb_bbox_min[0],
                   sb_bbox_max[1]-sb_bbox_min[1],
                   sb_bbox_max[2]-sb_bbox_min[2] ];   // ~[60.76, 95.68, 174.47]
sb_center      = [ (sb_bbox_min[0]+sb_bbox_max[0])/2,
                   (sb_bbox_min[1]+sb_bbox_max[1])/2,
                   (sb_bbox_min[2]+sb_bbox_max[2])/2 ]; // ~[0.312, 12.46, 102.53]

// --- principal member dimensions (from analysis OBBs) ---
body_obb_dims        = [164.95, 60.76, 25.93];  // harp_big_side_pivot (tapered box shell)
soundboard1_obb_dims = [158.73, 58.26,  0.59];  // harp_white_wood_01  (flat face)
soundboard2_obb_dims = [158.73, 56.69,  0.59];  // harp_white_wood_02  (flat face)
plank_obb_dims       = [157.99,  2.60,  0.71];  // harp_wood_plank     (flat bar)
inside_obb_dims      = [ 42.12, 27.29,  0.65];  // harp_wood_inside    (flat plate)
// inside1 (harp_wood_inside1) excluded -> neck-region piece (z 174.6-189.8)

// --- render quality ---
$fn = 48;

// ============================================================================
// ASSEMBLY  --  all 5 soundbox members at original world coords
// ============================================================================
module soundbox() {
    // body shell -- the bulk of the soundbox (tapered/curved box, hull loft)
    sb_harp_big_side_pivot();

    // soundboard faces (the two flat front plates)
    sb_harp_white_wood_01();
    sb_harp_white_wood_02();

    // central plank running the length of the box
    sb_harp_wood_plank();

    // inner lining (bass-bottom plate)
    sb_harp_wood_inside();
}

soundbox();

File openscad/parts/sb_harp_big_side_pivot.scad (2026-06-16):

// sb_harp_big_side_pivot - SOUNDBOX BODY = straight-sided HALF-CONE
// D cross-section in the world X(width)-Y(depth) plane: FLAT soundboard side at Y=yflat,
// arc belly bulging to +Y. Wings dropped (arc-only width). Straight sides = hull(bass,treble).
// Body rakes in Y-Z; the two caps sit at their world Z, so the hull reproduces the rake.
nh=48;
function _hc_arc(W,D,xc,yf)=[for(i=[0:nh]) let(t=180*i/nh)[ xc+(W/2)*cos(t), yf+D*sin(t) ]];
module _hc_cap(z,xc,yf,W,D,eps) translate([0,0,z]) linear_extrude(height=eps) polygon(_hc_arc(W,D,xc,yf));
module sb_harp_big_side_pivot(){
    eps=0.02;
    bz=15.856; bxc=0.312; byf=-32.440; bW=49.280; bD=30.077;
    tz=151.895; txc=0.312; tyf=52.058; tW=13.957; tD=8.078;
    hull(){ _hc_cap(bz,bxc,byf,bW,bD,eps); _hc_cap(tz,txc,tyf,tW,tD,eps); }
}
sb_harp_big_side_pivot();

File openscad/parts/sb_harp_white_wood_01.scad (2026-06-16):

// sb_harp_white_wood_01 — soundboard face (flat tapered plate)
//
// Construction choice: FLAT PLATE -> linear_extrude(thickness) of a 2D outline.
// Justification (from analysis JSON):
//   obb_dims = [158.728, 58.260, 0.586]. The third OBB extent (0.586) is ~270x
//   smaller than the other two -> a thin flat plate lying in the e0-e1 plane with
//   its thickness along e2. Every cross-section outline has an e2 spread of only
//   ~0.02-0.06 confirming the slab is essentially planar.
//   The outline is symmetric in e1 and tapers monotonically in width from 58.26
//   (at e0=-56.2) down to 16.86 (at e0=+102.5) -> a tapered trapezoid-ish plate.
//   So: build the tapered outline in the (e0,e1) plane and extrude it by the
//   measured thickness along e2. Placed at original world coords via multmatrix.

module sb_harp_white_wood_01() {
    // --- key dimensions (model world units), from JSON ---
    thickness = 0.5855474371629796;            // obb_dims[2], slab thickness (along e2)
    e2_mid    = (-0.06552327076825293 + 0.5200241663947267) / 2; // outline mid-plane offset in e2

    // principal frame (columns e1,e2,e0) + centroid, from JSON
    // world = centroid + u*e1 + v*e2 + w*e0 ; local: x=u(e1), y=v(e2), z=w(e0)
    // centroid
    cx = 0.44119784559796194;
    cy = -1.4524250851382396;
    cz = 64.66925852212562;
    // e1 (principal_axes[1])
    e1x = 0.9999999999999987;  e1y = 5.101571019845674e-08;  e1z = 1.1910700121443101e-08;
    // e2 (principal_axes[2])
    e2x = -3.7162652564615806e-08; e2y = 0.8510479848443533; e2z = -0.525087923582674;
    // e0 (principal_axes[0])
    e0x = -3.692431067464216e-08; e0y = 0.5250879235826725; e0z = 0.851047984844354;

    // --- tapered outline in the (e0 , e1) plane ---
    // each row: [s_along_e0, half_width_in_e1]   (outline is symmetric in e1)
    s_hw = [
        [ -56.210913273070176, 29.130 ],
        [ -29.756272516140438, 29.130 ],
        [  -3.3016317592107,   24.592 ],
        [  23.15300899771904,  18.213 ],
        [  49.607649754648776, 15.200 ],
        [  76.06229051157852,  11.716 ],
        [ 102.51693126850826,   8.427 ]
    ];
    n = len(s_hw);

    // build closed polygon in the (e1 , e0) plane: x = e1, y = e0
    // down the +e1 edge (top->bottom in e0), back up the -e1 edge
    pts_pos = [ for (i=[0:n-1])    [  s_hw[i][1], s_hw[i][0] ] ];
    pts_neg = [ for (i=[n-1:-1:0]) [ -s_hw[i][1], s_hw[i][0] ] ];
    poly = concat(pts_pos, pts_neg);   // (x=e1, y=e0)

    multmatrix([[e1x, e2x, e0x, cx],
                [e1y, e2y, e0y, cy],
                [e1z, e2z, e0z, cz],
                [0,   0,   0,   1]]) {
        // Local target frame: x=e1, y=e2(thickness), z=e0.
        // Extrude poly (x=e1, y=e0) along z by thickness, then rotate([90,0,0]):
        //   (x,y,z) -> (x, -z, y)  => local_x=e1, local_y=-thickness, local_z=e0.
        translate([0, e2_mid, 0])      // shift to outline mid-plane along local y (e2)
            rotate([90, 0, 0])         // map extrude axis -> local y, poly-y(e0) -> local z
                linear_extrude(height = thickness, center = true)
                    polygon(points = poly);
    }
}

sb_harp_white_wood_01();

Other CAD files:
openscad/parts/sb_harp_white_wood_02.scad
cad/assembly.scad
cad/brass/brass.scad
cad/frame/base.scad
cad/frame/neck.scad
cad/frame/pillar.scad
cad/frame/soundboard.scad
cad/frame/soundbox.scad
cad/params.scad
cad/scaffold/harp_scaffold.scad
cad/scaffold/soundbox_limacon.scad
cad/strings.scad
openscad/parts/sb_harp_wood_inside.scad
openscad/parts/sb_harp_wood_inside1.scad
openscad/parts/sb_harp_wood_plank.scad

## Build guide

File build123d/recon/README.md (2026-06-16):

# recon/ — faithful extraction of clements49.blend into build123d B-rep solids

Goal: turn the **actual** geometry of `clements49.blend` (the purchased TurboSquid
model, 541 objects / 87k verts) into clean build123d B-rep solids that match the real
shapes — so the harp can be parameterized, the 2 bass strings added, and the
acoustic/structural analysis re-run on faithful geometry. This complements the
*idealized* primitives under `build123d/parts/` (use those for clean parametrics; use
these when geometry must match the real model).

## Pipeline (two env-isolated stages)

The build123d env needs conda's libexpat (`build123d/py` sets `LD_LIBRARY_PATH`), but
that same lib breaks numpy/trimesh — so meshing and CAD run in **separate** Python envs:

1. **Export** per-object-family meshes from the blend (Blender 5.1 headless):
   `~/blender5/blender --background blender/clements49.blend --python <export>` joins each
   name-family (e.g. all `harp_string`) and writes `cad/parts_mesh/<family>.stl`.
2. **Slice** (`slice_part.py`, run with the **plain venv** `.venv/bin/python`): cut the
   mesh into `N` cross-sections along an axis; each section's largest-area polyline is
   closed (handles open shells like the soundbox), arc-length **resampled to `M` points**
   with consistent winding + start vertex (equal counts are what make the loft robust),
   and written as world-3D loops to `recon/sections/sec_<family>.json`.
3. **Loft** (`loft_part.py` / `loft_all.py` / `build_recon.py`, run with `build123d/py`):
   ThruSections (ruled) loft of the section faces → a B-rep solid → `recon/brep/<family>.brep`.

Regenerate everything: `build123d/py recon/build_recon.py` (needs `cad/parts_mesh/*.stl`).

## Functional mapping (see manifest.json for axis/N/M per part)

| function | blend family | notes |
|---|---|---|
| column | `harp_pole` | real **tapered/waisted** post — NOT a plain cylinder |
| neck | `harp_top_wood` | harmonic-curve S over the top |
| soundbox | `harp_big_side_pivot` | open shell; sections closed across the soundboard face |
| base_body | `harp_base_body` | watertight |
| base_bottom | `harp_base_bottom` | watertight |
| leg | `harp_leg` | watertight feet |
| strings | `harp_string` ×47 | endpoints already in `clements49_params.STRINGS` (+2 bass for the 49-set) |

Not yet reconstructed (decorative/mechanism): bolts, gold pedal box, pedals, pivots,
string-holes, inner planks, the small `pole_top_pivot` finial (Z 211.5→216.4).

## Verification

Each part is checked by **bbox + volume vs its source mesh** (recorded in manifest.json),
and the assembled `recon_harp()` was rendered (HLR side view) and visually confirmed to
read as a real concert pedal harp. All 6 frame parts loft to **valid** solids.

## Use

```python
import sys; sys.path.insert(0, "recon")
from parts_recon import recon_harp, recon_part, recon_frame
asm   = recon_harp(string_set=49)     # faithful frame + 49 strings
col   = recon_part("column")          # one part
```

## Known limitations / next

- **Drawing cleanliness**: ruled-loft surfaces show facet/ring seams under HLR (geometry
  is faithful; the lines are cosmetic). A silhouette-only render or smooth loft is future
  work; the clean idealized plates remain `build123d/clements47.svg` / `clements49.svg`.
- Geometry files (`*.stl`, `*.brep`, `sections/`) are **derived from the licensed model**
  and are gitignored — only the pipeline code + manifest are tracked. Regenerate locally.

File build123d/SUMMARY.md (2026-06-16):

# Clements 49 — build123d parametric harp: overnight summary

Goal: convert `clements49.blend` into a **parameterized build123d model** so the 2 bass
strings can be added and the acoustic/structural analysis re-run. Status below is split
into **SOLID** (built + independently verified) vs **APPROXIMATE/DESIGNED** (idealized or
a deliberate design choice, not a faithful trace of the mesh).

## How to run
- All build123d runs: `build123d/py <script.py>` (wrapper sets `LD_LIBRARY_PATH` for a
  libexpat fix and uses the venv with build123d 0.10). Plain `python3` won't import it.
- Parts: `build123d/parts/<part>.py` (each exposes `<part>()`). Shared schedule/dims:
  `build123d/clements49_params.py`. Assembly: `assembly.py` → `harp(string_set=49|47)`.
- Plates: `build123d/make_plates.py` → `clements47.svg`, `clements49.svg`.

## SOLID (verified)
- **Env**: build123d imports & runs; `project_to_viewport` HLR works on B-rep solids.
- **All 7 parts build as valid solids** (soundbox, soundboard, pillar, base, pedals,
  strings, neck). Bbox vs the mesh: base 0.1, neck 0.3, soundboard 4.8, pedals 2.4.
- **49 strings** = 47 endpoints **measured from the blend** + 2 bass extrapolated (A0,B0).
  `STRING_SET` toggle verified (47→47 rods, 49→49 rods). **ΣT = 9269.4 N** (from schedule).
- **Cavity volume = 49.7 L** measured from the parametric soundbox solid (~1% vs the mesh).
- **Plates** `clements47.svg` / `clements49.svg`: third-angle HLR (FRONT·SIDE·REAR row +
  TOP aligned above SIDE, column left in both), views-only, sized ~950 px. Render verified.
  Strings drawn as coloured overlay lines (C red, F blue, others dark gray).
- **Faithful mesh-traced parts** (`build123d/recon/`): 6 structural families extracted from
  the blend into **valid B-rep solids** (slice→loft, see recon/README.md), each verified by
  bbox+volume vs the mesh; assembled HLR side view confirmed to read as a real pedal harp.
  Correction: the real column (`harp_pole`) is a tapered/waisted post, not a cylinder.

## APPROXIMATE / DESIGNED (not a faithful mesh trace)
- Surfaces are **idealized parametric solids**, not the mesh surfaces: soundbox = clean
  straight-sided half-cone (wings dropped); soundboard = clean tapered plate; neck = spline
  S-curve slab + box foot (captures the harmonic curve approximately).
- **Pillar** = cylinder (diameter 9.27 = narrowest `harp_pole`, measured) + grooved
  Archimedean/helical spiral — a **design choice you requested**, not the original column.
- **Helmholtz A0 ≈ 70–85 Hz** is **ESTIMATED** — back sound-holes are not modeled yet.
- The plates are HLR of this **parametric reconstruction**, not a projection of the blend's
  own mesh lines (the blend has no curves; build123d HLR segfaults on meshes).

## Open / recommended next (needs your call)
1. **Frame expansion for the 2 bass strings** — biggest remaining item. Today the 49 vs 47
   difference is only the 2 extra string *rods*; the soundboard/neck/soundbox do **not** yet
   lengthen at the bass. Making the frame extent a function of `STRING_SET` would make the
   49 plate structurally different (longer bass corner), which is the real "add 2 strings".
2. **Back sound-holes** — model them to finalize A0/Helmholtz.
3. **Mesh-faithful drawing** (optional) — if you want a plate that *is* the original mesh
   outline, that's a separate pipeline (decimate→sew-to-solid, or the earlier custom HLR).

I paused autonomous work here (a clean, verified, committed milestone) rather than guess at
the frame-expansion, since it's a design decision and you've been steering the details.

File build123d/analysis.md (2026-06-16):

# Clements 49 — Acoustic + Structural Analysis (parametric model)

Driven entirely by `clements49_params.STRINGS` (49-string schedule) and
`parts/soundbox.py`. Adding/removing strings in `params_strings.json` +
`analysis/string_schedule.json` re-drives every number below — ΣT, the rake
distribution, and the soundboard load all recompute from the live data.

Units: model units (~8.86 mm/unit, `UNIT_MM = 8.8598`). `V_mm3 = V_units *
UNIT_MM**3`; `litres = V_mm3 / 1e6`.

## 1. Cavity volume + Helmholtz A0

**MEASURED (parametric solid, `soundbox()` — straight-sided half-cone loft):**
- V = **71483.4 model-units³** = **49,713,808 mm³** = **49.71 L**

**Cross-check vs reference mesh (`stl/soundbox_body.stl`, trimesh):**
- mesh V = 72339.8 units³ (mesh is NOT watertight; bbox 60.8×92.9×136.8 vs
  parametric 49.3×92.6×136.0).
- Difference ≈ **+1.2%** (mesh larger). The parametric body is a clean
  straight-sided half-cone (D-section, flat soundboard chord + elliptical
  belly); the mesh includes the slightly bulged back staves and wider X extent,
  so it reads marginally larger. Volumes agree to ~1%, confirming the
  parametric cavity.

**Helmholtz A0 (ESTIMATED — back sound-holes are NOT modeled yet):**
`f0 = (c/2π)·√(A / (V·L_eff))`, c = 343,000 mm/s, V = 49.71 L,
L_eff = wall t + flange end-correction (~1.7·r), assumed wall t ≈ 8 mm.
Hole area is the dominant unknown — these are assumptions, not measurements:

| assumed back holes | A (mm²) | L_eff (mm) | A0 (Hz) |
|---|---|---|---|
| 3 × ⌀40 mm | 3770 | 42.0 | **~73 Hz** |
| 3 × ⌀50 mm | 5890 | 50.5 | **~84 Hz** |
| 2 × ⌀60 mm | 5655 | 59.0 | **~76 Hz** |

So A0 lands in the **~70–85 Hz** band for typical harp sound-hole areas —
roughly D2–F2. To finalize A0, model the actual back sound-holes and feed their
true total area + wall thickness into the formula above.

## 2. Structural — string loads

From `params.STRINGS` (49 strings, all with `tension_N`):

- **ΣT = SIGMA_T_N = 9269.4 N** (sum of all 49 string tensions; recomputed sum
  matches exactly).
- per-string tension: **102.7 N (G7, treble) … 261.3 N**, mean 189.2 N.

**Rake distribution** (angle of each string's board→pin vector off the
soundboard long axis, ~+Z):
- range **0.8° … 6.4°**, mean **2.3°** (quartiles ~0.9° / 1.7° / 3.5°).
- Rake grows from bass (≈0.9°) toward treble (G7 ≈6.4°): the short treble
  strings splay most relative to the box axis.

**Load resolved at the soundboard anchors** (each string pulls along its
board→pin unit vector):
- in-plane, along board long axis (Z): **ΣT·|u_z| = 9261.3 N** — i.e. essentially
  all of ΣT pulls *along* the soundboard toward the neck. This is the dominant
  lengthwise load the box/neck/pillar must react.
- perpendicular, out of the soundboard face (along its ±Y normal):
  **ΣT·|u_y| = 66.4 N** — the small "lifting" component off the soundboard plane.
- scalar tension sum (reference): 9269.4 N.

Interpretation: the strings run almost parallel to the box axis (tiny Y
deflection), so the soundboard sees a large in-plane longitudinal pull (~9.26
kN) and only a small (~66 N) net out-of-plane pull. The perpendicular figure is
geometry-sensitive; the structurally governing number is ΣT ≈ **9.27 kN**
in-plane.

## 3. Measured vs estimated

| quantity | status | source |
|---|---|---|
| cavity volume 49.71 L | **measured** | `soundbox()` solid `.volume` × UNIT_MM³ |
| mesh volume 72340 units³ (+1.2%) | **measured** | trimesh on `stl/soundbox_body.stl` |
| ΣT = 9269.4 N | **measured** (from schedule) | `params.SIGMA_T_N` |
| tension range / rake distribution | **measured** (computed from params) | `STRINGS[*].board/pin/tension_N` |
| in-plane 9261.3 N / perp 66.4 N | **derived** (from params geometry) | board→pin direction × T |
| Helmholtz A0 ~70–85 Hz | **ESTIMATED** | needs real back sound-hole area + wall t |

**Re-analysis note:** all the above are functions of the live params. Add 2
strings to the schedule (+geometry) and ΣT, the load split, the rake range, and
(if box dims change) the cavity volume / A0 all recompute automatically by
re-running `_analysis_calc.py`.

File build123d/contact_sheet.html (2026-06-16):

# clements49 -- parametric harp build123d contact sheet

Isometric HLR projections (view dir 1,-1,1). Solid black = visible edges, grey dashes = hidden. Model units (~8.86 mm/unit), original world coords.

assembled harp

ASSEMBLY -- harp() 7 parts | bbox 73.5 x 124.2 x 216.4 | svg/harp_iso.svg

soundbox

soundbox -- half-cone loft valid | bbox 49.3 x 92.6 x 136.0 | svg/soundbox_iso.svg

soundboard

soundboard -- tapered plate loft valid | bbox 53.5 x 86.2 x 135.7 | svg/soundboard_iso.svg

pillar

pillar -- leaning ring loft (column) valid | bbox 48.4 x 32.4 x 204.2 | svg/pillar_iso.svg

base

base -- filleted box pedestal valid | bbox 60.2 x 61.1 x 15.5 | svg/base_iso.svg

pedals

pedals -- 7 fanned lever boxes valid | bbox 73.5 x 34.7 x 2.7 | svg/pedals_iso.svg

strings

strings -- 49 cylinder rods (param schedule) valid | bbox 3.1 x 83.5 x 194.3 | svg/strings_iso.svg

neck

neck -- spline-profile arm + foot valid | bbox 14.5 x 97.4 x 70.8 | svg/neck_iso.svg

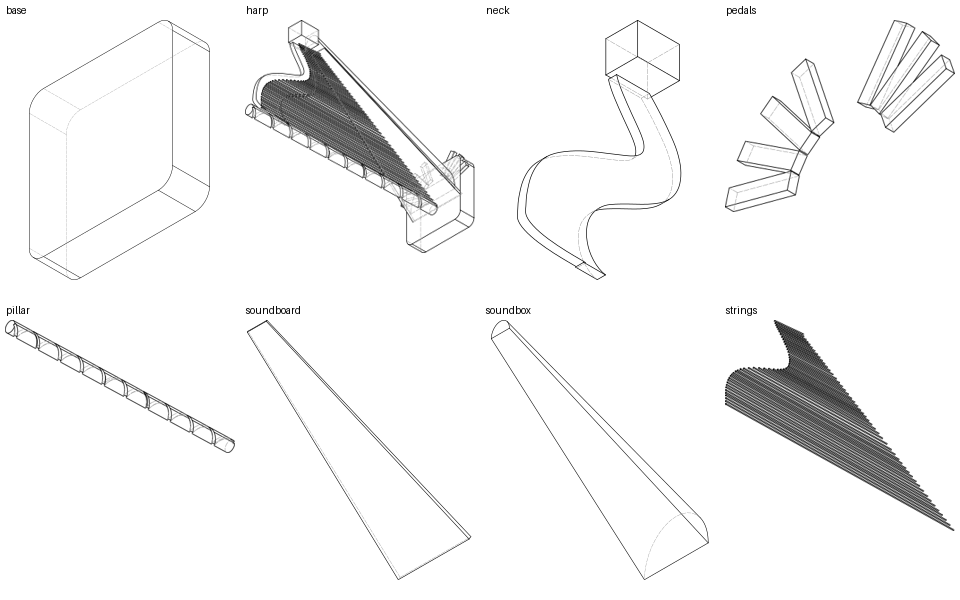
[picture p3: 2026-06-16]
build123d/contact_sheet.png

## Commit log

2026-06-15 Initial commit: Clements 49 parametric harp baseline
    Parametric OpenSCAD model (frame + brass) driven by the 49-string A0-G7
    schedule, structural/acoustic analysis, HLR drawing plate, and design docs.
    Purchased TurboSquid base model and mesh-derived binaries are gitignored
    (third-party licensed, not redistributable).
    [assembly.scad, base.scad, brass.scad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]
2026-06-15 Add soundbox attachment footprints (base seat + neck join)
    Completes NICE-TO-HAVE #6: soundbox-to-base and soundbox-to-neck attachment
    outlines (sliced at the actual ends) plus mating-part references.
2026-06-16 Parametric build123d harp + clements47/clements49 HLR plates
    Reverse-engineered the harp from clements49.blend into a parameterized build123d
    model (clean B-rep solids per part: half-cone soundbox, tapered soundboard, pillar,
    base, pedals, 49 strings, curved neck) driven by the 49-string A0-G7 schedule.
    STRING_SET toggle (47 baseline / 49 = +2 bass A0,B0) -> clements47.svg & clements49.svg
    third-angle HLR plates (front/side/rear + top). Per-part isometric SVGs, contact sheet,
    and acoustic/structural analysis (cavity 49.7 L, ΣT 9269 N).
    Env: build123d 0.10 in .venv (run via build123d/py for the libexpat fix);
    project_to_viewport HLR works on solids only (mesh import segfaults). venv, STL
    ex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
    [harp_scaffold.scad, params.scad, sb_harp_big_side_pivot.scad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]
2026-06-16 Plates: views-only third-angle layout, top aligned above side
    clements47.svg / clements49.svg: TOP view oriented (up=+X) to share the SIDE view's
    depth(Y) axis and placed directly above it (aligned); FRONT/SIDE/REAR row shares Z.
    Removed border, title block, and view labels per request; sheet sized to ~950px to
    fit a monitor. STRING_SET 47/49 toggle drives the 2-bass expansion.
2026-06-16 Pillar = cylinder + Archimedean spiral; fix top-view mirror (column left in both)
    pillar.py: plain cylinder shaft with a constant-pitch (Archimedean) helical spiral
    ridge swept up it, on the leaning column axis. make_plates: mirror the TOP view
    horizontally so its depth axis matches the SIDE -> column on the left and aligned in
    both top and side. NOTE: plates are HLR of the parametric build123d reconstruction
    (measured from clements49.blend), not a trace of the mesh's own lines.
2026-06-16 Pillar: diameter = narrowest pole (9.27, measured from blend), spiral grooved in
    R=4.635 (narrowest harp_pole diameter / 2, measured at z~79 in clements49.blend).
    Spiral changed from raised ridge to a groove cut into the shaft (shaft - swept helix tube).
    Plates regenerated.
2026-06-16 Verify all parts (render+bbox), refresh isos/assembly/contact sheet
    Independent pass: all 7 parts valid; neck is a clean harmonic S-curve (not a fallback);
    base/neck bbox match within 0.3, soundboard ~4.8, pedals ~2.4; pillar (~33 dev) and
    strings (~6.8) deviate by design (narrowest-diameter column; +2 bass strings).
    Regenerated per-part isometric SVGs + assembly + contact_sheet.png. Analysis (cavity
    49.7 L, ΣT 9269 N) unchanged by the pillar edit.
2026-06-16 Pillar: remove spiral (plain cylinder), move column left 14.2mm for 25mm A0 airgap
    Spiral removed -> plain cylinder at narrowest pole diameter (9.27). Column moved -Y
    (Y_CENTER -40.5 -> -42.104) so the lowest string A0 clears the pillar surface by
    PILLAR_AIRGAP_MM=25 (was 12.3 mm). assembly.harp gains include_strings flag (for
    upcoming coloured-string overlays). DIMENSION CHECK vs maker spec: height 191.8cm/75.5
    matches; ExW ~110.6cm vs 103, soundboard 51.6cm vs 58.4 -> model deeper & narrower-boarded.
2026-06-16 Plates: draw strings as coloured lines (C red, F blue, others dark gray)
    Frame drawn strings-less (assembly.harp include_strings=False) for the black HLR;
    strings overlaid as CONTINUOUS coloured layers via strings_by_color() + util.hlr_svg
    overlays= (projected with the same camera so they register). No black string strokes.
2026-06-16 recon: faithful extraction of clements49.blend into build123d B-rep solids
    Two-stage env-isolated pipeline (Blender export -> trimesh slice in plain venv ->
    build123d ThruSections loft): traces the REAL geometry of 6 structural part families
    into valid B-rep solids, verified by bbox+volume vs the source mesh and a visual HLR
    side view (reads as a real pedal harp).
    Key finding: the column (harp_pole) is a tapered/waisted post, NOT the 9.27 cylinder
    previously assumed. Soundbox (harp_big_side_pivot) is an open shell; slicer closes
    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
2026-06-16 recon: embed Ctrl+Shift+E STL-export hotkey into clements49.blend
    Per TODO.md: select object(s) in the viewport, press Ctrl+Shift+E -> export them
    as one STL named from the active object. blender_stl_export.py is the addon (kept
    as tracked source); embed_hotkey.py installs it as a register-on-load text datablock
    inside the .blend (Method B, headless); verify_hotkey.py reopens and exercises it.
    SCALE=1.0 (NOT the TODO's 1000): the scene is in model units (~8.86 mm/unit), not
    metres, so 1.0 keeps exports consistent with clements49_params / recon breps. Verified
    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
2026-06-16 Plates: faithful clean-silhouette clements49/47.svg from curated mesh export
    Replaces the idealized-parts plate with one built directly from your hand-selected
    frame export (blender/clements49.stl -> split_frame.py -> 15 bodies). make_plate_silhouette.py
    projects each body's triangles per view and unions them (shapely) so only the true
    OUTER SILHOUETTE is stroked -- faithful geometry (tapered column, real neck/soundbox)
    with zero loft/facet seams. Strings overlaid as coloured lines (C red, F blue, others
    gray); 49 vs 47 differ by the 2 bass strings. Views-only layout (front|side|rear +
    top above side, aligned), ~950px. Pure plain-venv (trimesh+shapely), no build123d/OCP.
    Top-view crossing i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
2026-06-16 Add single-pin silhouette plate (build123d/pin.svg)
    make_pin_plate.py pulls one full-length tuning pin from hardware_pins.stl, centers it,
    and draws PROFILE (the turned lathe outline) + END view (the circle). Measured pin:
    73.5 mm long x 7.2 mm dia. Confirms the pin is a clean revolve part.
2026-06-16 Add parametric pin part (revolve, instanced per string)
    parts/pins.py: pin() revolves the measured (x,r) profile (recon/pin_profile.json,
    extracted from the blend) about X -> one exact turned pin (73.5 x 7.2 mm, valid solid),
    with length_scale/radial_scale knobs to adjust the casting design. pins(string_set)
    instances it at every string's pin_xyz + measured offset; verified 49/47 toggle and
    that the 49 pins trace the neck harmonic curve. This is the brass lost-wax/lost-PLA
    casting pattern (1 pattern, 49 castings).
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2026-06-16 Pins: design a clean TURNABLE pin (replace art-model bumps) + turning drawing
    parts/pins.py now revolves a DESIGNED axisymmetric blank (drive boss Ø6 -> seating
    collar Ø9 -> shaft Ø7.2 -> chamfered tip) with a drilled Ø1.6 cross-hole, instead of
    tracing the model's noisy shape. Dims in recon/pin_design.json (shared). Valid solid,
    73.5mm, pins(49/47) place one per string. recon/make_pin_turning.py renders the
    dimensioned lathe drawing -> pin.svg (full section + centreline + Ø callouts + lengths).
    length_scale etc. replaced by explicit named feature dims you can edit for the casting.
2026-06-16 Pins: revert to the ORIGINAL pin shape (measured, cleaned) per request
    Undo the invented design (collar + drilled hole were not in the model). pin() now
    revolves the measured profile from clements49.blend, cleaned of mesh noise only
    (recon/pin_profile.json): rounded head Ø5.7, neck groove Ø3.8, shaft Ø7.0, and the
    real string-winding groove Ø5.6 @ 66mm (which the redesign had wrongly replaced with a
    drilled hole). Fixed profile-closure bug (axis edge was cutting diagonally -> solid came
    out 62.6mm; now correct 73.5mm, verified). make_pin_turning.py + pin.svg redrawn from
    the measured profile, dimensioned. Removed the invented pin_design.json.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
2026-06-16 pin.svg: show the worm-drive tuner + co-moulded receiver as a mating pair
    pin.svg is now the geared-tuner pair (the design that replaces the simple pin):
    RECEIVER (cast brass, co-moulded in the flax neck -- post bore, worm bore, resin-keying
    anchor holes) beside the TUNER (string post + worm wheel + hex-driven worm, 10:1
    self-locking). make_tuner_plate.py reads recon/tuner_params.json. The simple-pin turning
    drawing remains available via make_pin_turning.py.
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2026-06-16 Add cylinder_pole.py: replace harp_pole with a simple cylinder
    Replaces harp_pole's mesh with a 64-facet cylinder of the narrowest pole diameter
    (9.914 units / 87.8mm), along the fitted pillar centreline, from the pole top (z211.5)
    down to the bottom of harp_pole_base (z15.49). Material kept; verified 128 verts.
    Applied to clements49.blend (backup: clements49.blend.precyl).
2026-06-16 Add box_pole.py: replace harp_pole cylinder with a thin rectangular beam
    Cross-section Y = full pillar diameter (~10.08), X = half (~5.04), along the same leaning
    centreline axis from pole top (z211.5) to bottom of harp_pole_base (z15.49). Shortest-arc
    orient keeps faces ~world X/Y; follows the lean. 8-vert box, material kept. Applied to
    clements49.blend (backup: clements49.blend.prebox).
2026-06-16 Replace harp_base_limacon with dimpled+slotted version (outer a=2b, inner a=1.5b)
    Actually import the built limacon into clements49.blend (prior iterations only wrote /tmp
    renders). Inner is a true dimpled limacon a=1.5b same size as outer a=2b (concave dimple
    on the pillar side), pedal slots cut through on the pedal side. 2592 verts. Backup:
    clements49.blend.prelima2.
2026-06-16 recon: limacon pedal-slot tooling + in-place mesh swap
    replace_mesh_keeploc.py swaps a new STL onto harp_base_limacon while preserving its
    (slid) transform. Final working approach: harp_base_body is a thin BAND split into 7
    segments by the pedal-slot gaps (angles 22/45/66/87/278/297/317 deg from its centroid);
    cut matching gaps into the limacon band so the 7 harp_pedal_* stems slide through.
    (cut_pedal_slots.py = the boolean approach that over-cut; kept for reference.)
